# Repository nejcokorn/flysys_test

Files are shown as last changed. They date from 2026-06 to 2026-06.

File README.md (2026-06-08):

# FlySys Hardware Plan

Updated: 2026-06-08

This folder is intentionally a planning workspace only. The next hardware build will be created from scratch in Atopile. Old EasyEDA, KiCad, generated production files, and JLC-specific draft outputs are not part of the active design.

## Goal

Build a compact FlySys variometer board with:

- BLE-first telemetry and configuration.
- Accurate pressure-based vertical-speed sensing.
- 6-axis inertial sensing for filtering/orientation support.
- LiPo charging and battery operation.
- Loud firmware-controlled audio output.
- USB mass-storage device access for logs/configuration.
- Power button, hidden BOOT/RESET recovery controls, green power LED, blue BLE pairing LED, USB, and software-first firmware update access without debug pads.

## Selected Components

| Function | Selection | Supplier note |
| --- | --- | --- |
| MCU/BLE/Wi-Fi/USBMSD | Espressif `ESP32-S3-WROOM-1U-N8` | Use ESP32-S3 because USBMSD needs configurable USB device support. `N8` provides 8 MB flash and has no PSRAM. The `1U` variant uses the module U.FL/I-PEX MHF1 connector for an off-board antenna. |
| External antenna | Pulse `ANTX200P001B24003` | Off-board 2.4 GHz adhesive flat patch antenna for the WROOM-1U U.FL/I-PEX MHF1 connector. It is a DigiKey order item, not a PCB footprint. |
| Pressure sensors | 2 x Bosch `BMP581` | Dual altitude/variometer pressure sensors on the same I2C bus. `U5` uses address `0x46`; `U6` uses address `0x47`. |
| 6-axis IMU | Bosch `BMI323` | Primary accelerometer/gyro. |
| Magnetometer | Not fitted | Keep unpopulated I2C pads or optional footprint for future magnetometer. |
| Charger / power path | TI `BQ24075RGTR` | 1S LiPo charger with power-path management. |
| 3.3 V regulator | TI `TLV75533PDBVR` | Replaces `AP2112K-3.3TRG1` because AP2112 was 0 stock in the DigiKey.si audit. Recheck current and thermal margin with ESP32-S3 peaks. Add local bulk capacitance near the module. |
| USB | GCT `USB4105-GF-A` + ST `USBLC6-2SC6Y` | USB-C 2.0 receptacle and automotive/AEC-Q101 USB ESD for charging, ESP32-S3 native USB, USBMSD, logs, and flashing. |
| Audio | Same Sky `CSS-J4D20-SMT-TR` + `AO3400A` N-MOSFET | Externally driven SMD magnetic transducer from the old device BOM. Drive from the 1S battery/SYS rail; keep firmware tone, carrier-duty, and envelope control. |
| User input | C&K `KMR211NG LFS` | Momentary active-low tactile switch for power/user input plus hidden BOOT and RESET service switches. Final actuator and pinhole geometry still depends on enclosure height. |
| Indicators | Lite-On `LTST-C190GKT` + `LTST-C190TBKT` | 0603 LEDs: green always-on `+3V3` power-present indicator, blue firmware-controlled BLE pairing/advertising indicator. The blue LED is driven from `SYS` with a GPIO-controlled low-side MOSFET. |
| Battery | JST `S2B-PH-SM4-TB` | 2-pin JST-PH right-angle SMD header. Confirm protected pack and cable polarity. |
| Firmware update | Application-level updater + hidden ESP32-S3 BOOT/RESET recovery | Normal users update through firmware while USB or another supported link is connected. Debug pads are not fitted; hidden BOOT+RESET remains the recovery fallback for the ESP32-S3 ROM USB bootloader. |

## DigiKey.si Availability Audit

Initial audit checked: 2026-05-31. Audio and LED changes rechecked: 2026-06-01. Stock changes quickly; recheck before ordering.

| Function | MPN | DigiKey cut-tape part | Observed availability | Status |
| --- | --- | --- | --- | --- |
| MCU/BLE/Wi-Fi/USBMSD | `ESP32-S3-WROOM-1U-N8` | `1965-ESP32-S3-WROOM-1U-N8CT-ND` | Recheck before ordering | Selected external-antenna module |
| External antenna | `ANTX200P001B24003` | `311-1553-ND` | Recheck before ordering | Off-board U.FL/I-PEX MHF1 adhesive 2.4 GHz antenna |
| Pressure sensors | `BMP581` | `828-BMP581CT-ND` | Recheck before ordering | Qty 2 selected |
| 6-axis IMU | `BMI323` | `828-BMI323CT-ND` | 663 in stock | Selected |
| Charger / power path | `BQ24075RGTR` | `296-38874-1-ND` | 3,702 in stock | Selected |
| 3.3 V LDO | `TLV75533PDBVR` | `296-50411-1-ND` | 110,688 in stock | Selected |
| USB-C receptacle | `USB4105-GF-A` | `2073-USB4105-GF-ACT-ND` | 126,702 in stock | Selected |
| USB ESD | `USBLC6-2SC6Y` | `497-11882-1-ND` | 35,783 in stock | Selected automotive/AEC-Q101 part; LCSC `C2969755` |
| Battery connector | `S2B-PH-SM4-TB` | `455-S2B-PH-SM4-TBCT-ND` | 71,350 in stock | Selected |
| Loud SMD buzzer | `CSS-J4D20-SMT-TR` | `102-1198-1-ND` | 2,332 in stock | Selected old-device buzzer: externally driven magnetic transducer, 90 dB at 3.6 V, 5 cm, 80 mA, 3.1 kHz |
| N-MOSFETs | `AO3400A` | `785-1000-1-ND` | 168,023 in stock | Low-side drivers for buzzer PWM, blue BLE pairing LED switching, and power-latch control |
| Battery switch P-MOSFET | `DMP3098L-7` | `DMP3098LDICT-ND` | Recheck before ordering | High-side hard-off switch between battery connector and internal `BAT` rail |
| Power-start diodes | `1N4148W-7-F` | `1N4148W-FDICT-ND` | Recheck before ordering | Diode isolation for power button, battery switch gate, and charger `SYSOFF` |
| User button | `KMR211NG LFS` | `CKN10243CT-ND` | 44,917 in stock | Selected |
| Power LED | `LTST-C190GKT` | `160-LTST-C190GKTCT-ND` | 1,068,260 in stock | Selected 0603 green LED, 2.1 V typical Vf |
| BLE LED | `LTST-C190TBKT` | `160-1646-1-ND` | 92,246 in stock | Selected 0603 blue LED for BLE pairing/advertising indication, 3.3 V typical Vf |
| Resistors | Yageo `RC0603FR` 1% 0603 family | Value-specific | `RC0603FR-0710KL` observed at 9,468,329 in stock | Use same family for 100R, 1k, 3k, 5.1k, 10k, 100k, 1M as needed |
| 100 nF decoupling capacitor | Samsung `CL10B104KB8NNNC` | `1276-1000-1-ND` | 9,953,497 in stock | Selected family |
| Other ceramics | Samsung CL-series MLCCs | Value-specific | Not individually locked yet | Select exact 1 uF, 10 uF, and 220 nF parts during Atopile binding |

Main audit result: all selected active semiconductors, sensors, connector choices, audio parts, button, LED, and common passives are available from DigiKey.si.

## Baseline Electrical Architecture

- `USB_VBUS`: USB-C 5 V input to charger and USB VBUS sense divider/comparator.
- `SYS`: BQ24075 system output.
- `BAT_RAW`: protected 1S LiPo positive terminal at the connector.
- `BAT`: switched internal battery rail after the hard-off P-MOSFET.
- `+3V3`: TLV75533 output powering ESP32-S3, both BMP581 sensors, BMI323, and optional magnetometer pads.
- `I2C_SCL`, `I2C_SDA`: shared sensor bus for BMP581 `U5`, BMP581 `U6`, BMI323, and DNP magnetometer option.
- `USB_OTG_DP`, `USB_OTG_DM`: USB full-speed pair to ESP32-S3 native USB pins (`GPIO20` D+, `GPIO19` D-).
- `BUZZER_VM`: battery/SYS-powered audio rail feeding the buzzer; no boost in the baseline.
- `BUZZER_PWM`: ESP32-S3 PWM-capable GPIO to the MOSFET gate.
- `PWR_SW_N`: raw active-low power switch node.
- `PWR_BTN_N`: diode-isolated active-low button input to ESP32-S3.
- `BOOT_USER_BTN_N`: ESP32-S3 GPIO0 boot strap, pulled low by the hidden BOOT service button for ROM bootloader recovery.
- `BAT_SENSE`: high-value divider from switched `BAT` to ESP32-S3 ADC-capable GPIO; it has no DC path to `BAT_RAW` when the hard-off switch is open.
- `POWER_LED`: low-current green `+3V3` rail indicator with series resistor. It is on whenever `+3V3` is up and is not firmware-controlled.
- `BLE_LED`: low-current blue indicator for BLE pairing/advertising mode only. Firmware should drive `BLE_LED_PWM` active only while connectable BLE advertising/pairing is active and keep it low or high-Z otherwise. Because the blue LED has high forward voltage, prefer `SYS` plus a current-limit resistor and a small GPIO-controlled low-side switch instead of direct `+3V3` GPIO drive.
- `EN`, `BOOT`: hidden physical RESET and BOOT service controls for ESP32-S3 ROM bootloader recovery only.

## USBMSD / Storage Plan

USBMSD is now a baseline requirement. Use ESP32-S3 native USB OTG device mode with the ESP-IDF TinyUSB MSC class.

Route the USB-C D+/D- pair to ESP32-S3 `GPIO20`/`GPIO19`, keep the ESD part near the connector, and add a USB VBUS monitor path because this is a battery-powered, self-powered USB device.

Initial storage options:

- Internal flash FAT partition for small configuration import/export and short log files.
- External SPI flash, SPI NAND, or microSD if host-visible logs need materially more capacity or write endurance.

Do not let firmware and the USB host write the same mounted filesystem at the same time. Define a mode switch or mount arbitration before implementing firmware.

## Firmware Update UX

Normal firmware update is software-first. When USB is connected, application
firmware should expose an update path such as USB MSC drag-and-drop firmware
copy, a USB CDC update tool, BLE DFU, or OTA. The image must be validated before
activation, and firmware should use OTA partitions with rollback so a failed
image can revert automatically.

USB attach is allowed to power the ESP32-S3 electrically. If `USB_VBUS_SENSE`
shows USB present and the user has not pressed `POWER`, firmware enters
USB-attached idle mode instead of starting the vario application. In this mode,
do not start vario sensing, BLE advertising, buzzer output, logging, or normal
flight behavior. Only minimal charging/status indication, the firmware update
endpoint, and an optional command to start normal mode should run.

Pressing `POWER` while USB is connected records user intent and starts the normal
application. The hidden `BOOT` (`GPIO0`) and `RST` (`EN`) controls remain behind
service access only. Recovery sequence: connect USB-C, hold hidden `BOOT`, press
and release hidden `RST`, release `BOOT`, then flash with the ESP32-S3 native USB
ROM bootloader tool.

## Audio Plan

The buzzer must be loud enough for a paragliding vario used in open air with wind noise. Treat acoustic output as a primary requirement, not a secondary indicator.

Use an externally driven passive SMD transducer so firmware keeps control over pitch, cadence, envelope, mute profiles, and sink/climb tone patterns. Do not use an internally driven active buzzer.

Selected audio path:

- Transducer: `CSS-J4D20-SMT-TR`, externally driven magnetic SMD transducer from the old device BOM, 90 dB at 3.6 V, 5 cm, 3.1 kHz, about 80 mA at rated drive.
- Driver: `AO3400A` low-side N-MOSFET, with the buzzer powered from the 1S battery/SYS rail and the MOSFET gate driven by one ESP32-S3 PWM GPIO.

This matches the old `MX270_MiniUP` firmware model: one output-compare PWM channel generated the audio carrier, `beep->volume` changed the carrier duty, and the vario queue changed the beep envelope/cadence. Port that control model to ESP32-S3 LEDC or MCPWM.

Use the battery/SYS rail, not raw USB VBUS. A normal 1S Li-ion/LiPo pack is 4.2 V full and about 3.6-3.7 V nominal; that fits the buzzer's 3-5 V operating range. Confirm BQ24075 `SYS` behavior so the buzzer never sees an out-of-range USB-derived rail.

Drive the buzzer near its 3.1 kHz rated frequency for maximum SPL. For lower volume, prefer carrier-duty control and audible envelope control; avoid detuning far from resonance just to reduce volume. The old firmware's tone table can be reused as a behavioral reference, but final tones should be revalidated against this buzzer in the enclosure.

Add a gate resistor, gate pulldown, local bulk capacitance near the buzzer supply, and a footprint option for coil clamp/snubber parts. Keep the buzzer current loop compact and scope the first PCB for ringing and EMI while the buzzer is running.

The enclosure must include a real acoustic outlet or sound channel. Verify SPL after the PCB is installed in the actual enclosure, because the port, chamber volume, venting, clothing, helmet, and mounting orientation can dominate the result.

## Sensor Plan

Use two BMP581 barometers and one BMI323 as the fitted sensor stack.

`U5` straps `SDO` to `GND` for BMP581 I2C address `0x46`; `U6` straps `SDO` to `+3V3` for address `0x47`. Both sensors strap `CSB` high for I2C mode and have separate interrupt nets, `BMP581_1_INT` and `BMP581_2_INT`.

Do not fit a magnetometer for the first Atopile board. The core variometer behavior depends on pressure and vertical-motion filtering, not absolute compass heading. Without a magnetometer, yaw/heading can drift; that is acceptable for this baseline.

Keep an unpopulated future magnetometer option with:

- `+3V3`
- `GND`
- `I2C_SCL`
- `I2C_SDA`
- Optional `MAG_INT`

Place the optional magnetometer pads away from USB shield, charger, buzzer, battery current loops, steel screws, and magnets.

## Layout Constraints

- Put the ESP32-S3-WROOM-1U-N8 so its U.FL/I-PEX MHF1 connector is accessible for the off-board antenna cable. Provide coax strain relief and keep the antenna away from battery metal, buzzer metal, enclosure metal, and the user's body as much as the enclosure allows.
- Put both BMP581 sensors near the pressure vent and away from heat, board flex, adhesive, conformal coating, and direct buzzer airflow.
- Put BMI323 near the board center in a mechanically stable area and document axis orientation.
- Keep sensor supply decoupling close to each VDD/VDDIO pin.
- Keep USB D+/D- short, impedance-conscious, protected by ESD near the connector, and routed to ESP32-S3 `GPIO20`/`GPIO19`.
- Include USB VBUS monitoring suitable for self-powered USB device behavior.
- Give the buzzer a clear acoustic outlet; do not bury the port in a sealed or foam-covered enclosure pocket.
- Keep buzzer switching current and charger return currents away from sensor ground return.
- Avoid assigning functional loads to ESP32-S3 boot strapping pins, USB pins, and flash/PSRAM-reserved pins until boot behavior and the exact module variant are checked.

## Firmware Impact

- Port board support from Arduino Nano 33 BLE Sense Rev2 / nRF52840 assumptions to ESP32-S3.
- Use ESP32-S3 BLE stack and keep transmission duty cycle low in production.
- Add USBMSD using ESP-IDF TinyUSB MSC over ESP32-S3 native USB OTG.
- Define the USBMSD storage backend and host-visible filesystem.
- Prevent concurrent writes between firmware logging/config code and the mounted USB host filesystem.
- Decide whether USB presents MSC only, CDC+MSC composite, or a boot/mode-selected function.
- Add software-first firmware update handling with image validation and OTA partition rollback.
- On USB attach from off state, enter USB-attached idle mode until `PWR_BTN_N` is pressed or a supported start command is received.
- In USB-attached idle mode, keep vario sensing, BLE normal operation, buzzer output, and logging inactive.
- Add direct dual-BMP581 driver support for I2C addresses `0x46` and `0x47`, including separate `BMP581_1_INT` and `BMP581_2_INT` handling.
- Add direct BMI323 driver support.
- Remove required magnetometer reads from the baseline firmware path.
- Rework GPIO mapping for ESP32-S3, including `BUZZER_PWM`, `PWR_BTN_N`, `PWR_HOLD`, `BAT_SENSE`, `BLE_LED_PWM`, I2C, USB, `EN`, and `BOOT`.
- Add configurable audio profiles for vario use: climb cadence, sink alarm, mute, startup check, and volume/power-saving modes.
- Port the old single-PWM buzzer model, then retune frequency and volume tables around the `CSS-J4D20-SMT-TR` response on the new PCB.
- Revalidate sensor axis mapping and calibration on the actual PCB.

## Open Decisions

- Protected LiPo pack and cable polarity.
- USBMSD storage backend: internal flash FAT partition vs external flash/NAND/microSD.
- USB device mode policy: MSC only, CDC+MSC composite, boot/mode-selected function, and the exact software update endpoint.
- Final volume-control policy: envelope levels, quiet mode, and startup volume.
- Enclosure acoustic outlet, port orientation, and measured SPL after installation.
- Button actuator/enclosure mechanics.
- Final ESP32-S3 GPIO map after strapping-pin, USB-pin, and reserved-pin review.
- Whether `ESP32-S3-WROOM-1U-N8` without PSRAM is sufficient for the final USBMSD firmware.
- RF/EMC certification path for the selected 4.4 dBi external antenna. Espressif's module certification guidance recommends antennas no higher than the certified antenna gain, so this antenna choice may require additional testing.
- TLV75533 current and thermal margin with ESP32-S3 RF peaks and USB-attached operation.
- Whether charger status pins need LEDs or only test pads.
- Final Atopile package/footprint sources and exact passive values.

## Atopile Build Order

1. Create Atopile project scaffold.
2. Add verified packages for ESP32-S3-WROOM-1U-N8, two BMP581 sensors, BMI323, BQ24075, TLV75533, USB-C, USB ESD, LiPo connector, CSS-J4D20 buzzer, MOSFET driver, button, green power LED, blue BLE pairing LED, passives, and the BOM-only external antenna.
3. Capture power path and 3.3 V rail.
4. Capture ESP32-S3 native USB OTG, USB VBUS sense, `EN`, `BOOT`, and hidden service bootloader buttons.
5. Capture both BMP581 sensors and BMI323 on shared I2C.
6. Add unpopulated magnetometer I2C pads or optional footprint.
7. Add the selected USBMSD storage backend if external storage is selected.
8. Capture loud audio and user I/O.
9. Assign supplier/manufacturer metadata for audit.
10. Run electrical/package checks before PCB routing.

## Atopile Project Status

Atopile is now the active project source in this repo:

- `ato.yaml`: Atopile 0.15.7 project config.
- `main.ato`: FlySysVario schematic source and Atopile `RectangularBoardShape` board outline.
- `parts/`: generated and local part definitions, including local draft footprints for battery, buzzer, MOSFETs, signal diodes, buttons, and optional magnetometer pads.
- `layouts/default/default.kicad_pcb`: Atopile-generated layout artifact used by the Atopile Autolayout panel.
- `docs/components-and-placement.md`: component map, passive explanations, and placement intent.

Current modeled nets include USB-C, USB ESD, BQ24075 power path, P-MOS battery hard-off switch, TLV75533 3.3 V rail, ESP32-S3 native USB, I2C sensor bus, two BMP581 barometers, BMI323, battery connector, switched battery/USB sense dividers, buzzer MOSFET driver, always-on green power LED, blue BLE pairing LED low-side switch, power/user button, hidden BOOT and RESET service buttons, and optional future magnetometer pads. See `docs/firmware-update-ux.md` for the software-first update flow and recovery fallback.

`ato --non-interactive build --standalone main.ato:FlySysVario` completes the
current Atopile source workflow. The default layout build still needs a layout
artifact migration after the WROOM-1U swap; `ato --non-interactive build`
passes electrical verification but fails while loading `layouts/default/default.kicad_pcb`.
The 90 mm x 45 mm board outline is defined in `main.ato` with
`RectangularBoardShape`, so the Atopile Autolayout panel has a board boundary to
place and route against. The remaining warnings are expected for local or
DigiKey-only parts because the current picker support is not covering those
local packages. Before production, verify the local draft footprints for
`ESP32-S3-WROOM-1U-N8`, `S2B-PH-SM4-TB`, `CSS-J4D20-SMT-TR`, `AO3400A`,
`DMP3098L`, `1N4148W`, `KMR211NG LFS`, and optional magnetometer pads against
manufacturer land patterns and enclosure mechanics.

## Source Links

- Atopile project structure: https://docs.atopile.io/atopile-0.14.x/essentials/5-project-structure
- Atopile language reference: https://docs.atopile.io/atopile-0.14.x/essentials/1-the-ato-language
- ESP32-S3-WROOM-1/WROOM-1U datasheet: https://documentation.espressif.com/esp32-s3-wroom-1_wroom-1u_datasheet_en.pdf
- DigiKey.si ESP32-S3-WROOM-1U-N8: https://www.digikey.si/en/products/detail/espressif-systems/ESP32-S3-WROOM-1U-N8/16162635
- DigiKey.si Pulse ANTX200P001B24003: https://www.digikey.si/en/products/detail/pulse-electronics/ANTX200P001B24003/3927174
- ESP-IDF ESP32-S3 USB Device Stack / TinyUSB MSC: https://docs.espressif.com/projects/esp-usb/en/latest/esp32s3/usb_device.html
- ESP-IDF ESP32-C3 USB Serial/JTAG fixed-function note: https://docs.espressif.com/projects/esp-idf/en/release-v5.2/esp32c3/api-guides/usb-serial-jtag-console.html
- Bosch BMP581: https://www.bosch-sensortec.com/en/products/environmental-sensors/pressure-sensors/bmp581/
- Bosch BMP581 datasheet / land pattern: https://www.bosch-sensortec.com/media/boschsensortec/downloads/datasheets/bst-bmp581-ds004.pdf
- DigiKey.si BMP581: https://www.digikey.si/en/products/detail/bosch-sensortec/BMP581/16036134
- Bosch BMI323: https://www.bosch-sensortec.com/en/products/motion-sensors/imus/bmi323/
- DigiKey.si BMI323: https://www.digikey.si/en/products/detail/bosch-sensortec/BMI323/16719593
- TI BQ24075: https://www.ti.com/product/BQ24075
- DigiKey.si BQ24075RGTR: https://www.digikey.si/en/products/detail/texas-instruments/BQ24075RGTR/2047273
- DigiKey.si TLV75533PDBVR: https://www.digikey.si/en/products/detail/texas-instruments/TLV75533PDBVR/9356541
- DigiKey.si USB4105-GF-A: https://www.digikey.si/en/products/detail/gct/USB4105-GF-A/11198441
- DigiKey.si USBLC6-2SC6Y: https://www.digikey.si/en/products/detail/stmicroelectronics/USBLC6-2SC6Y/2819177
- DigiKey.si S2B-PH-SM4-TB: https://www.digikey.si/en/products/filter/headers-male-pins/314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
- DigiKey.si CSS-J4D20-SMT-TR: https://www.digikey.si/en/products/detail/same-sky-formerly-cui-devices/CSS-J4D20-SMT-TR/504819
- DigiKey.si AO3400A: https://www.digikey.si/en/products/detail/alpha-omega-semiconductor-inc/AO3400A/1855772
- DigiKey.si KMR211NG LFS: https://www.digikey.si/en/products/detail/c-k/Y78B21120FP/2176482
- DigiKey.si LTST-C190GKT: https://www.digikey.si/en/products/detail/lite-on-inc/LTST-C190GKT/269230
- DigiKey.si LTST-C190TBKT: https://www.digikey.si/en/products/detail/lite-on-inc/LTST-C190TBKT/388529
- DigiKey.si RC0603FR resistor family: https://www.digikey.si/en/products/filter/chip-resistor-surface-mount/52
- DigiKey.si CL10B104KB8NNNC: https://www.digikey.si/en/products/detail/samsung-electro-mechanics/CL10B104KB8NNNC/3886658

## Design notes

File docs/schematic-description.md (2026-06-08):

# FlySys Schematic Description

Updated: 2026-06-08

This document describes the KiCad schematic in text form. The schematic file is
`kicad/flysys_vario.kicad_sch`; the Atopile source net plan is `main.ato`.

## Functional Blocks

FlySys is a small BLE/USB variometer board built around `U4`, an
`ESP32-S3-WROOM-1U-N8` module with an external U.FL/I-PEX MHF1 antenna
connector. Power enters from USB-C at `USB1` or from a LiPo
battery at `J1`. `U1` manages LiPo charging and the system power path, `U3`
generates the regulated `+3V3` rail, `U5` and `U6` measure pressure for
altitude/vario data, `U2` provides IMU motion data, and `BZ1` gives loud
acoustic feedback.

The board uses the following main nets:

| Net | Meaning |
| --- | --- |
| `USB_VBUS` | 5 V from USB-C connector. Feeds charger input and USB VBUS sense divider. |
| `BAT_RAW` | LiPo battery positive terminal at `J1`, before the hard-off battery switch. |
| `BAT` | Switched internal battery rail after `Q4`. Feeds charger battery pin and battery ADC divider only while the battery switch is on. |
| `SYS` | Charger power-path output. Feeds 3.3 V regulator and high-current buzzer/blue LED loads when the system is on. |
| `+3V3` | Regulated logic rail for ESP32-S3, both pressure sensors, IMU, pull-ups, and the green power LED. |
| `CHG_SYSOFF` | BQ24075 ship-mode control. High disconnects battery from `SYS`; low enables battery-to-`SYS` operation. |
| `PWR_SW_N` | Raw active-low power button node from `SW1`, isolated from MCU and latch nodes by diodes. |
| `PWR_BTN_N` | Isolated active-low power/user button input read by the MCU on `IO7`. |
| `USB_VBUS_SENSE` | Divided USB VBUS monitor read by the MCU on `IO2`. Firmware uses it to detect USB-attached idle/update mode. |
| `PWR_HOLD` | MCU `IO10` output that can release the self-latching power circuit by driving `PWR_HOLD_GATE` low. |
| `BMP581_1_INT` | Interrupt output from `U5` BMP581 to MCU `IO4`. |
| `BMP581_2_INT` | Interrupt output from `U6` BMP581 to MCU `IO16`. |
| `BAT_SWITCH_GATE` | Gate of the battery high-side P-channel MOSFET `Q4`. |
| `GND` | Common ground and USB shield reference. |

## USB-C And ESD

`USB1` is the USB-C device connector. `CC1` and `CC2` are each pulled down to
ground by `R9` and `R10`, both 5.1 kohm, so the board presents itself as a USB
device/sink.

USB data exits the connector as `USB_DP_CONN` and `USB_DM_CONN`, passes through
`D1` (`USBLC6-2SC6Y`) for ESD protection, then continues to the ESP32-S3 as
`USB_OTG_DP` and `USB_OTG_DM`. `D1` must stay physically between `USB1` and
`U4`, close to the connector, so ESD current is shunted before it reaches the
MCU.

The USB-C shell/mechanical pads are tied to `GND`. The local USB footprint maps
all shell pads to the same symbol pin so KiCad does not leave shield pads
unconnected during PCB update.

## Charger And Power Path

`U1` (`BQ24075RGTR`) receives `USB_VBUS` on `IN`, connects to the switched
internal battery rail on `BAT`, and produces the system rail on `OUT`/`SYS`.
The charger is enabled by tying `nCE` low. `EN1`, `EN2`, `TS`, `ISET`, `ILIM`,
and `TMR` are configured with fixed resistors, so the current limits and timer
behavior are set in hardware.

`Q4` (`DMP3098L`) is a high-side P-channel MOSFET between `BAT_RAW` and `BAT`.
`R28` pulls `BAT_SWITCH_GATE` up to `BAT_RAW`, so the default battery-only state
physically disconnects the battery from the BQ24075 `BAT` pin and from the
`BAT_SENSE` divider. In this state the board has no intentional DC battery load;
only MOSFET/diode leakage remains.

`SYSOFF` is still used as the BQ24075 power-path off control. `R23` pulls
`CHG_SYSOFF` up to the switched `BAT` rail, while `Q3` pulls it low when the
power latch is active. Pressing `SW1` grounds `PWR_SW_N`; `D3` pulls
`BAT_SWITCH_GATE` low to turn `Q4` on, and `D4` pulls `CHG_SYSOFF` low so
`SYS` turns on from the battery. Once `+3V3` is up, `R24` pulls
`PWR_HOLD_GATE` high and turns on both `Q3` and `Q5`, which latches
`CHG_SYSOFF` and `BAT_SWITCH_GATE` low after `SW1` is released. `R26` keeps the
latch off before `+3V3` is present.

Firmware can shut the board down from battery power by driving `IO10`
(`PWR_HOLD`) low through `R25`; this turns off `Q3` and `Q5`, after which `R23`
and `R28` return the charger and battery switch to their off states. During
normal operation and during the ESP32-S3 ROM bootloader, `PWR_HOLD` may remain
high impedance because `R24` provides the hardware hold.

When USB is present, the BQ24075 can still power `SYS` from `USB_VBUS`. Firmware
should keep the latch active while battery charging is desired so `Q4` is on and
the BQ24075 `BAT` pin is connected to the pack.

`nCHG` and `nPGOOD` are open-drain charger status outputs. `R13` and `R19` pull
them up to `+3V3`, and the MCU reads them on GPIOs. These nets should not be
pulled to `SYS` because the ESP32-S3 GPIOs are 3.3 V only.

`J1` is the 2-pin LiPo connector. `BAT_POS` goes to `BAT_RAW`, and `BAT_NEG`
goes to `GND`. The final build must confirm connector polarity against the
actual battery harness before ordering or assembly.

## 3.3 V Regulation

`U3` (`TLV75533PDBVR`) converts `SYS` into `+3V3`. The regulator enable pin is
tied to `SYS`, so the 3.3 V rail is on whenever `SYS` is present. On battery
power, `SYS` is present only after `CHG_SYSOFF` is pulled low by `SW1` or `Q3`.

`+3V3` powers the ESP32-S3 module, both BMP581 pressure sensors, BMI323 IMU,
I2C pull-ups, charger status pull-ups, the always-on green power LED, and
button/latch pull-ups.

## ESP32-S3 MCU

`U4` is the main controller. It uses native USB through `USB_OTG_DP` and
`USB_OTG_DM`, reads battery and USB voltage dividers, reads charger status, runs
the I2C sensor bus, drives the buzzer PWM MOSFET, and drives the BLE
pairing/advertising LED MOSFET.

The fitted module is `ESP32-S3-WROOM-1U-N8`. Its onboard U.FL/I-PEX MHF1
connector mates to the BOM-only external antenna `ANT1`
(`ANTX200P001B24003`). `ANT1` is not a PCB footprint. The selected antenna has
4.4 dBi gain, so RF/EMC approval needs a separate review against the target
certification path.

`EN` has a 10 kohm pull-up (`R16`) and 100 nF capacitor (`C4`) for a simple reset
RC network. `SW3` pulls `EN` low for a hidden service reset button labeled
`RST` on the PCB.

`BOOT_USER_BTN_N` is pulled up by `R6` and pulled low by `SW2`. `SW2` is a
hidden service `BOOT` button, not a normal user update control. To enter the
ESP32-S3 ROM USB bootloader for recovery, connect USB-C, hold `SW2` (`BOOT`),
press and release `SW3` (`RST`), then release `BOOT`. If a service setup must
keep the board powered from battery before USB is attached, press `SW1` first to
latch power; recovery flashing still requires USB. No debug pads are fitted.

`SW1` is the active-low power button on `PWR_SW_N`. `D2` lets the MCU read this
button as `PWR_BTN_N` on `IO7` while preventing `BAT_RAW` or latch nodes from
feeding the unpowered MCU in hard-off.

## Firmware Update And USB-Attached Idle UX

Normal firmware update is software-first. Application firmware should expose an
update endpoint such as USB MSC drag-and-drop, USB CDC update tooling, BLE DFU,
or OTA. Firmware must validate the image before activating it and should use OTA
partitions with rollback so a failed update returns to the previous working
image.

USB attach is allowed to power the ESP32-S3 electrically through the charger
power path. On boot, firmware must read `USB_VBUS_SENSE` and the current or
persisted power-intent state. If USB is present and the user has not pressed
`POWER`, firmware enters USB-attached idle mode rather than starting the vario
application.

In USB-attached idle mode, firmware must not start pressure/IMU vario sensing,
BLE advertising or normal telemetry, buzzer output, flight logging, or normal
flight behavior. Only minimal charging/status indication, the firmware update
endpoint, and an optional command to start normal mode should run. Pressing
`SW1` drives `PWR_BTN_N` low; firmware records this user intent and starts the
normal application.

The hidden `BOOT` + `RST` sequence remains the documented recovery fallback only
when the application updater is unavailable or application firmware is broken.
See `docs/firmware-update-ux.md` for the service flow and verification plan.

## Sensor Bus

`U5` (`BMP581`), `U6` (`BMP581`), and `U2` (`BMI323`) share the I2C bus:

| Net | MCU | Loads |
| --- | --- | --- |
| `I2C_SCL` | ESP32-S3 `IO8` | `U5 SCK`, `U6 SCK`, `U2 SCX`, pull-up `R17` |
| `I2C_SDA` | ESP32-S3 `IO9` | `U5 SDI`, `U6 SDI`, `U2 SDX`, pull-up `R18` |

Both pull-ups are 4.7 kohm to `+3V3`. `U5 SDO` is tied to `GND` for BMP581 I2C
address `0x46`; `U6 SDO` is tied to `+3V3` for address `0x47`. `BMI323 SDO` is
tied to `GND`. All sensor chip-select pins are tied high so the devices remain
in I2C mode. Sensor interrupt pins are routed independently to ESP32 GPIOs for
firmware use.

## Buzzer Driver

`BZ1` is powered from `SYS`, not from `+3V3`, so it can use the higher available
system voltage and avoid loading the LDO. `Q1` (`AO3400A`) is a low-side
N-channel MOSFET controlled by ESP32 PWM through `R8`. `R7` pulls the MOSFET
gate down so the buzzer stays off while the MCU is reset or booting.

The buzzer current loop is `SYS -> BZ1 -> Q1 -> GND`. This loop must be compact
and kept away from the pressure sensor and I2C lines.

## LEDs

`LED2` is the green power LED. It is powered from `+3V3` through `R20`, then
returns directly to `GND`. It is a power-present indicator and is on whenever
`+3V3` is up; firmware does not control it.

`LED1` is the blue BLE pairing LED. It is powered from `SYS` through `R5` and
switched by `Q2`, another low-side `AO3400A`. `R4` is the series gate resistor,
and `R3` is the gate pulldown. This keeps the LED off while the ESP32-S3 GPIO is
high impedance. Firmware should drive `BLE_LED_PWM` active only while BLE
pairing/connectable advertising mode is active, and keep it low or high-Z
otherwise.

## Capacitors And Their Roles

| Ref | Value | Net | Role |
| --- | --- | --- | --- |
| `C14` | 1 uF | `USB_VBUS` to `GND` | USB input decoupling. It supplies short input-current pulses and should sit close to `USB1`/`U1 IN`. |
| `C1` | 10 uF | `BAT` to `GND` | Switched battery rail bulk capacitance. It stabilizes the charger battery pin after `Q4` is on. |
| `C13` | 10 uF | `SYS` to `GND` | Main system rail bulk. It helps the charger power-path output handle load changes from the LDO and buzzer. |
| `C7` | 1 uF | `SYS` to `GND` | LDO input capacitor. It must be placed at `U3 IN/GND` to keep the regulator stable. |
| `C8` | 1 uF | `+3V3` to `GND` | LDO output capacitor. It must be placed at `U3 OUT/GND` to meet regulator stability requirements. |
| `C9` | 10 uF | `+3V3` to `GND` | ESP32-S3 local bulk capacitor. It supports RF and CPU current bursts. |
| `C10` | 100 nF | `+3V3` to `GND` | ESP32-S3 high-frequency decoupling. It should be very close to the module power pin. |
| `C12` | 100 nF | `U5 BMP581 VDD` to `GND` | First pressure sensor core decoupling. Place next to `U5`. |
| `C11` | 100 nF | `U5 BMP581 VDDIO` to `GND` | First pressure sensor I/O decoupling. Place next to `U5`. |
| `C15` | 100 nF | `U6 BMP581 VDD` to `GND` | Second pressure sensor core decoupling. Place next to `U6`. |
| `C16` | 100 nF | `U6 BMP581 VDDIO` to `GND` | Second pressure sensor I/O decoupling. Place next to `U6`. |
| `C6` | 100 nF | `BMI323 VDD` to `GND` | IMU core decoupling. Place next to `U2`. |
| `C5` | 100 nF | `BMI323 VDDIO` to `GND` | IMU I/O decoupling. Place next to `U2`. |
| `C3` | 10 uF | `SYS` to `GND` | Local buzzer reservoir. Place close to `BZ1` and `Q1` so buzzer current does not disturb the rest of `SYS`. |
| `C4` | 100 nF | `EN` to `GND` | ESP32-S3 enable/reset RC capacitor with `R16`. Place close to `U4 EN`. |
| `C2` | 100 nF | `BAT_SENSE` to `GND` | ADC filter for the switched-battery divider midpoint. Place near `R1`/`R2` and the MCU ADC input. |

## No-Connect Rules

Every intentionally unused schematic pin must be marked as no-connect in KiCad.
Do not silently leave an unused pin without either a net label or a no-connect
marker.

`NC` means no copper connection: do not tie the pin to `GND`, `+3V3`, `SYS`, or
any other net unless the datasheet explicitly asks for it. Do not add test pads
to `NC` pins unless the schematic is updated to document that future option.

For this design, the intentionally unused pins are:

| Component | Pins | Required treatment |
| --- | --- | --- |
| `USB1` | `A8`, `B8` | USB-C SBU pins are unused. Leave floating and mark no-connect. |
| `U3` | `4` | TLV75533 `NC` pin. Leave floating and mark no-connect. |
| `U4` | `8`, `15`, `16`, `19`, `20`, `21`, `22`, `23`, `24`, `25`, `26`, `28`, `29`, `32`, `33`, `34`, `35`, `36`, `37` | Unused ESP32-S3 GPIO/module pins. Leave floating and mark no-connect. Do not tie unused GPIOs to rails in hardware. |
| `U2` | `2`, `3`, `10`, `11` | BMI323 datasheet NC pins. Leave floating and mark no-connect. |

The USB-C shell pads are not `NC`; they are part of the connector shield and are
tied to `GND`.

## Component Pin Connection Instructions

The tables below define what every component pin must connect to in the
schematic and PCB. `NC` rows follow the no-connect rules above.

### Connectors And Protection

| Ref | Pin | Pin name | Connect to | Instruction |
| --- | --- | --- | --- | --- |
| `USB1` | `1` | `EH` | `GND` | USB-C shell/edge hardware ground. All shell mounting pads in the footprint are mapped to this grounded pin. |
| `USB1` | `A1`, `A12`, `B1`, `B12` | `GND` | `GND` | Connector signal grounds. Tie directly to the ground plane. |
| `USB1` | `A4`, `A9`, `B4`, `B9` | `VBUS` | `USB_VBUS` | USB 5 V input. Route to `U1 IN`, `D1 VBUS`, `C14`, and USB VBUS sense divider. |
| `USB1` | `A5` | `CC1` | `CC1` | Connect only to `R9`, then to `GND`. |
| `USB1` | `B5` | `CC2` | `CC2` | Connect only to `R10`, then to `GND`. |
| `USB1` | `A6`, `B6` | `DP1`, `DP2` | `USB_DP_CONN` | Connector-side USB D+. Route to `D1` first. |
| `USB1` | `A7`, `B7` | `DN1`, `DN2` | `USB_DM_CONN` | Connector-side USB D-. Route to `D1` first. |
| `USB1` | `A8`, `B8` | `SBU1`, `SBU2` | `NC` | Leave floating; this board does not use USB-C alternate modes. |
| `D1` | `1` | `IO1_A` | `USB_DP_CONN` | Connector-side D+ input to ESD device. |
| `D1` | `2` | `GND` | `GND` | Short ESD return to ground. |
| `D1` | `3` | `IO2_A` | `USB_DM_CONN` | Connector-side D- input to ESD device. |
| `D1` | `4` | `IO2_B` | `USB_OTG_DM` | MCU-side D- output from ESD device. |
| `D1` | `5` | `VBUS` | `USB_VBUS` | ESD reference to USB VBUS. |
| `D1` | `6` | `IO1_B` | `USB_OTG_DP` | MCU-side D+ output from ESD device. |
| `J1` | `1` | `BAT+` | `BAT_RAW` | LiPo positive terminal before the hard-off battery switch. Confirm pack polarity before assembly. |
| `J1` | `2` | `BAT-` | `GND` | LiPo negative terminal. |

### Power Management

| Ref | Pin | Pin name | Connect to | Instruction |
| --- | --- | --- | --- | --- |
| `U1` | `1` | `TS` | `CHG_TS` | Connect to `R15` then `GND`. This is the fixed TS bias for no pack thermistor. |
| `U1` | `2`, `3` | `BAT` | `BAT` | Battery charger node. Keep short to `J1` and `C1`. |
| `U1` | `4` | `nCE` | `GND` | Charger enabled. |
| `U1` | `5` | `EN2` | `SYS` | Charger input-current mode strap. |
| `U1` | `6` | `EN1` | `GND` | Charger input-current mode strap. |
| `U1` | `7` | `nPGOOD` | `nPGOOD` | Open-drain status output. Pull up through `R19` to `+3V3`; also route to `U4`. |
| `U1` | `8` | `VSS` | `GND` | Ground. |
| `U1` | `9` | `nCHG` | `nCHG` | Open-drain charge status output. Pull up through `R13` to `+3V3`; also route to `U4`. |
| `U1` | `10`, `11` | `OUT` | `SYS` | Charger system output. Keep wide to `U3`, `C13`, buzzer, and LED load. |
| `U1` | `12` | `ILIM` | `CHG_ILIM` | Connect to `R11` then `GND`. |
| `U1` | `13` | `IN` | `USB_VBUS` | USB input power. Keep short to `USB1` and `C14`. |
| `U1` | `14` | `TMR` | `CHG_TMR` | Connect to `R14` then `GND`. |
| `U1` | `15` | `SYSOFF` | `CHG_SYSOFF` | Ship-mode control. High disconnects battery from `SYS`; low enables battery-to-`SYS` operation. |
| `U1` | `16` | `ISET` | `CHG_ISET` | Connect to `R12` then `GND`. |
| `U1` | `17` | `EP` | `GND` | Exposed pad. Stitch to ground plane for thermal and electrical return. |
| `Q4` | `1` | `G` | `BAT_SWITCH_GATE` | P-channel battery switch gate. Pull high to `BAT_RAW` for off, pull low to connect `BAT_RAW` to `BAT`. |
| `Q4` | `2` | `S` | `BAT_RAW` | P-channel source to raw battery connector positive. |
| `Q4` | `3` | `D` | `BAT` | P-channel drain to switched internal battery rail. |
| `Q5` | `1` | `G` | `PWR_HOLD_GATE` | N-channel gate driven by the hardware hold node. |
| `Q5` | `2` | `S` | `GND` | Low-side switch source. |
| `Q5` | `3` | `D` | `BAT_SWITCH_GATE` | Pulls `Q4` gate low while the power latch is active. |
| `U3` | `1` | `IN` | `SYS` | LDO input. Place `C7` at this pin. |
| `U3` | `2` | `GND` | `GND` | LDO ground. |
| `U3` | `3` | `EN` | `SYS` | LDO enabled whenever `SYS` is present. |
| `U3` | `4` | `NC` | `NC` | Leave floating and mark no-connect. |
| `U3` | `5` | `OUT` | `+3V3` | Regulated logic rail. Place `C8` at this pin. |

### ESP32-S3 Module

| Ref | Pin | Pin name | Connect to | Instruction |
| --- | --- | --- | --- | --- |
| `U4` | `1`, `40`, `41` | `GND`, `EPAD/GND` | `GND` | Tie all module grounds and the exposed pad to the ground plane. Do not leave any ground pad isolated. |
| `U4` | `2` | `3V3` | `+3V3` | Main module supply. Place `C9` and `C10` close to the module. |
| `U4` | `3` | `EN` | `EN` | Module enable/reset net with `R16` pull-up and `C4` to ground. |
| `U4` | `4` | `IO4` | `BMP581_1_INT` | First pressure sensor interrupt input from `U5`. |
| `U4` | `5` | `IO5` | `BMI323_INT1` | IMU interrupt input 1. |
| `U4` | `6` | `IO6` | `BMI323_INT2` | IMU interrupt input 2. |
| `U4` | `7` | `IO7` | `PWR_BTN_N` | Active-low power/user button input from `SW1`. |
| `U4` | `8` | `IO15` | `NC` | Leave floating and mark no-connect. |
| `U4` | `9` | `IO16` | `BMP581_2_INT` | Second pressure sensor interrupt input from `U6`. |
| `U4` | `10` | `IO17` | `BUZZER_PWM` | PWM output to `Q1` through `R8`. |
| `U4` | `11` | `IO18` | `BLE_LED_PWM` | BLE pairing/advertising LED control output to `Q2` through `R4`. |
| `U4` | `12` | `IO8` | `I2C_SCL` | I2C clock with pull-up `R17`. |
| `U4` | `13` | `IO19` | `USB_OTG_DM` | Native USB D-. Route as controlled short USB pair with pin 14. |
| `U4` | `14` | `IO20` | `USB_OTG_DP` | Native USB D+. Route as controlled short USB pair with pin 13. |
| `U4` | `15` | `IO3` | `NC` | Leave floating and mark no-connect; this is a strapping-sensitive GPIO. |
| `U4` | `16` | `IO46` | `NC` | Leave floating and mark no-connect; do not drive this strapping-sensitive GPIO high during reset. |
| `U4` | `17` | `IO9` | `I2C_SDA` | I2C data with pull-up `R18`. |
| `U4` | `18` | `IO10` | `PWR_HOLD` | Power-hold release output. Leave high-Z/high for normal hold; drive low to shut down from battery. |
| `U4` | `19`, `20`, `21`, `22` | `IO11`, `IO12`, `IO13`, `IO14` | `NC` | Leave floating and mark no-connect. |
| `U4` | `23`, `24`, `25` | `IO21`, `IO47`, `IO48` | `NC` | Leave floating and mark no-connect. |
| `U4` | `26` | `IO45` | `NC` | Leave floating and mark no-connect; this is a strapping-sensitive GPIO. |
| `U4` | `27` | `IO0` | `BOOT_USER_BTN_N` | Boot-mode strap/recovery net with pull-up `R6`; not connected to `SW1`. |
| `U4` | `28`, `29` | `IO35`, `IO36` | `NC` | Leave floating and mark no-connect. |
| `U4` | `30` | `IO37` | `nCHG` | Charger status input from `U1`, pulled up to `+3V3` by `R13`. |
| `U4` | `31` | `IO38` | `nPGOOD` | Charger power-good input from `U1`, pulled up to `+3V3` by `R19`. |
| `U4` | `32`, `33`, `34`, `35` | `IO39`, `IO40`, `IO41`, `IO42` | `NC` | Leave floating and mark no-connect. |
| `U4` | `36` | `RXD0` | `NC` | Debug pads are not fitted. Leave floating and mark no-connect. |
| `U4` | `37` | `TXD0` | `NC` | Debug pads are not fitted. Leave floating and mark no-connect. |
| `U4` | `38` | `IO2` | `USB_VBUS_SENSE` | USB VBUS ADC sense divider midpoint. Firmware uses this to enter USB-attached idle/update mode. |
| `U4` | `39` | `IO1` | `BAT_SENSE` | Battery ADC sense divider midpoint with filter `C2`. |

### Sensors

| Ref | Pin | Pin name | Connect to | Instruction |
| --- | --- | --- | --- | --- |
| `U5` | `1` | `VDDIO` | `+3V3` | First pressure sensor I/O supply. Decouple with `C11`. |
| `U5` | `2` | `SCK` | `I2C_SCL` | I2C clock. |
| `U5` | `3`, `8`, `9` | `VSS` | `GND` | Pressure sensor grounds. |
| `U5` | `4` | `SDI` | `I2C_SDA` | I2C data. |
| `U5` | `5` | `SDO` | `GND` | I2C address strap for address `0x46`. |
| `U5` | `6` | `CSB` | `+3V3` | I2C mode strap. |
| `U5` | `7` | `INT` | `BMP581_1_INT` | Interrupt output to `U4.4` / `IO4`. |
| `U5` | `10` | `VDD` | `+3V3` | First pressure sensor core supply. Decouple with `C12`. |
| `U6` | `1` | `VDDIO` | `+3V3` | Second pressure sensor I/O supply. Decouple with `C16`. |
| `U6` | `2` | `SCK` | `I2C_SCL` | I2C clock. |
| `U6` | `3`, `8`, `9` | `VSS` | `GND` | Pressure sensor grounds. |
| `U6` | `4` | `SDI` | `I2C_SDA` | I2C data. |
| `U6` | `5` | `SDO` | `+3V3` | I2C address strap for address `0x47`. |
| `U6` | `6` | `CSB` | `+3V3` | I2C mode strap. |
| `U6` | `7` | `INT` | `BMP581_2_INT` | Interrupt output to `U4.9` / `IO16`. |
| `U6` | `10` | `VDD` | `+3V3` | Second pressure sensor core supply. Decouple with `C15`. |
| `U2` | `1` | `SDO` | `GND` | I2C address strap. |
| `U2` | `2`, `3`, `10`, `11` | `NC` | `NC` | Leave floating and mark no-connect. |
| `U2` | `4` | `INT1` | `BMI323_INT1` | Interrupt output to `U4.9`. |
| `U2` | `5` | `VDDIO` | `+3V3` | IMU I/O supply. Decouple with `C5`. |
| `U2` | `6` | `GNDIO` | `GND` | IMU I/O ground. |
| `U2` | `7` | `GND` | `GND` | IMU core ground. |
| `U2` | `8` | `VDD` | `+3V3` | IMU core supply. Decouple with `C6`. |
| `U2` | `9` | `INT2` | `BMI323_INT2` | Interrupt output to `U4.10`. |
| `U2` | `12` | `CSB` | `+3V3` | I2C mode strap. |
| `U2` | `13` | `SCX` | `I2C_SCL` | I2C clock. |
| `U2` | `14` | `SDX` | `I2C_SDA` | I2C data. |

### User Interface And Drivers

| Ref | Pin | Pin name | Connect to | Instruction |
| --- | --- | --- | --- | --- |
| `SW1` | `1`, `2` | `A` | `PWR_SW_N` | Button side connected to raw active-low power switch net. |
| `SW1` | `3`, `4` | `B` | `GND` | Button side connected to ground. |
| `SW2` | `1`, `2` | `A` | `BOOT_USER_BTN_N` | Hidden service BOOT button side connected to ESP32-S3 GPIO0 strap. |
| `SW2` | `3`, `4` | `B` | `GND` | BOOT button pulls GPIO0 low for ROM bootloader recovery entry. |
| `SW3` | `1`, `2` | `A` | `EN` | Hidden service RESET/RST button side connected to ESP32-S3 enable/reset net. |
| `SW3` | `3`, `4` | `B` | `GND` | RST button pulls `EN` low. |
| `BZ1` | `1` | `+` | `SYS` | Buzzer positive terminal. Keep current path local to `C3`. |
| `BZ1` | `2` | `-` | `BUZZER_NEG` | Buzzer switched return to `Q1.3`. |
| `Q1` | `1` | `G` | `BUZZER_GATE` | Gate drive from `R8`, pulldown by `R7`. |
| `Q1` | `2` | `S` | `GND` | Low-side switch source. |
| `Q1` | `3` | `D` | `BUZZER_NEG` | Low-side switch drain to buzzer negative terminal. |
| `Q2` | `1` | `G` | `BLE_LED_GATE` | Gate drive from `R4`, pulldown by `R3`. |
| `Q2` | `2` | `S` | `GND` | Low-side switch source. |
| `Q2` | `3` | `D` | `BLE_LED_K` | Low-side switch drain to blue BLE pairing LED cathode. |
| `Q3` | `1` | `G` | `PWR_HOLD_GATE` | Gate drive from the hardware hold node. |
| `Q3` | `2` | `S` | `GND` | Low-side switch source. |
| `Q3` | `3` | `D` | `CHG_SYSOFF` | Pulls BQ24075 `SYSOFF` low while the power latch is active. |
| `D2` | `1` | `K` | `PWR_SW_N` | Isolates the raw power switch node from the MCU button input. |
| `D2` | `2` | `A` | `PWR_BTN_N` | Lets `SW1` pull the MCU button input low when the board is on. |
| `D3` | `1` | `K` | `PWR_SW_N` | Lets `SW1` pull `BAT_SWITCH_GATE` low during power-on. |
| `D3` | `2` | `A` | `BAT_SWITCH_GATE` | Diode-isolated start path for `Q4` gate. |
| `D4` | `1` | `K` | `PWR_SW_N` | Lets `SW1` pull `CHG_SYSOFF` low during power-on. |
| `D4` | `2` | `A` | `CHG_SYSOFF` | Diode-isolated start path for BQ24075 `SYSOFF`. |
| `LED1` | `1` | `K` | `BLE_LED_K` | Blue BLE pairing LED cathode to `Q2.3`. |
| `LED1` | `2` | `A` | `BLE_LED_A` | Blue BLE pairing LED anode through `R5` to `SYS`. |
| `LED2` | `1` | `-` | `GND` | Always-on green power LED cathode. |
| `LED2` | `2` | `+` | `POWER_LED_A` | Always-on green power LED anode through `R20` to `+3V3`. |

### Resistors And Capacitors

| Ref | Pin 1 connects to | Pin 2 connects to | Instruction |
| --- | --- | --- | --- |
| `R9` | `CC1` | `GND` | USB-C CC1 sink pulldown. |
| `R10` | `CC2` | `GND` | USB-C CC2 sink pulldown. |
| `R15` | `CHG_TS` | `GND` | Charger TS fixed bias. |
| `R12` | `CHG_ISET` | `GND` | Charger current-set resistor. |
| `R11` | `CHG_ILIM` | `GND` | Charger input-current limit resistor. |
| `R14` | `CHG_TMR` | `GND` | Charger timer resistor. |
| `R13` | `nCHG` | `+3V3` | Pull-up for charger `nCHG`. |
| `R19` | `nPGOOD` | `+3V3` | Pull-up for charger `nPGOOD`. |
| `R16` | `EN` | `+3V3` | ESP32 enable pull-up. |
| `R6` | `BOOT_USER_BTN_N` | `+3V3` | ESP32 boot strap pull-up. |
| `R23` | `CHG_SYSOFF` | `BAT` | Pulls `SYSOFF` high after the switched battery rail is present. |
| `R24` | `PWR_HOLD_GATE` | `+3V3` | Pulls the latch gate high after `+3V3` starts, so bootloader mode stays powered without firmware. |
| `R25` | `PWR_HOLD` | `PWR_HOLD_GATE` | Power-hold MOSFET gate series resistor. |
| `R26` | `PWR_HOLD_GATE` | `GND` | Keeps `Q3`/`Q5` off while `+3V3` is absent. |
| `R27` | `PWR_BTN_N` | `+3V3` | Pull-up for the active-low power/user button input. |
| `R28` | `BAT_SWITCH_GATE` | `BAT_RAW` | Pulls the P-channel battery switch gate high so the raw battery is disconnected by default. |
| `R2` | `BAT` | `BAT_SENSE` | Battery divider top resistor. |
| `R1` | `BAT_SENSE` | `GND` | Battery divider bottom resistor. |
| `R22` | `USB_VBUS` | `USB_VBUS_SENSE` | USB VBUS divider top resistor. |
| `R21` | `USB_VBUS_SENSE` | `GND` | USB VBUS divider bottom resistor. |
| `R17` | `I2C_SCL` | `+3V3` | I2C SCL pull-up. |
| `R18` | `I2C_SDA` | `+3V3` | I2C SDA pull-up. |
| `R8` | `BUZZER_PWM` | `BUZZER_GATE` | Buzzer MOSFET gate series resistor. |
| `R7` | `BUZZER_GATE` | `GND` | Buzzer MOSFET gate pulldown. |
| `R5` | `SYS` | `BLE_LED_A` | Blue BLE pairing LED current limit resistor. |
| `R4` | `BLE_LED_PWM` | `BLE_LED_GATE` | BLE pairing LED MOSFET gate series resistor. |
| `R3` | `BLE_LED_GATE` | `GND` | BLE pairing LED MOSFET gate pulldown. |
| `R20` | `+3V3` | `POWER_LED_A` | Always-on green power LED current limit resistor. |
| `C14` | `USB_VBUS` | `GND` | USB input capacitor. |
| `C1` | `BAT` | `GND` | Switched battery bulk capacitor. |
| `C13` | `SYS` | `GND` | System rail bulk capacitor. |
| `C7` | `SYS` | `GND` | LDO input capacitor. |
| `C8` | `+3V3` | `GND` | LDO output capacitor. |
| `C9` | `+3V3` | `GND` | ESP32 local bulk capacitor. |
| `C10` | `+3V3` | `GND` | ESP32 high-frequency decoupling capacitor. |
| `C12` | `+3V3` | `GND` | `U5` BMP581 VDD decoupling capacitor. |
| `C11` | `+3V3` | `GND` | `U5` BMP581 VDDIO decoupling capacitor. |
| `C15` | `+3V3` | `GND` | `U6` BMP581 VDD decoupling capacitor. |
| `C16` | `+3V3` | `GND` | `U6` BMP581 VDDIO decoupling capacitor. |
| `C6` | `+3V3` | `GND` | BMI323 VDD decoupling capacitor. |
| `C5` | `+3V3` | `GND` | BMI323 VDDIO decoupling capacitor. |
| `C3` | `SYS` | `GND` | Local buzzer bulk capacitor. |
| `C4` | `EN` | `GND` | ESP32 enable/reset capacitor. |
| `C2` | `BAT_SENSE` | `GND` | Battery ADC filter capacitor. |

## Connection And Layout Constraints

- Do not route USB data directly to the MCU before `D1`; the ESD device must be
  first in line after the connector.
- Keep `USB_OTG_DP` and `USB_OTG_DM` short, parallel, and length-similar. Avoid
  stubs around the ESD part.
- Keep `USB_VBUS`, `BAT`, and `SYS` wider than normal signal nets. These nets
  carry charging, regulator, and buzzer current.
- Do not feed ESP32 GPIO pull-ups from `SYS`; use `+3V3` only.
- Keep `C7` and `C8` tight to `U3`; moving them away can make the LDO unstable.
- Keep each 100 nF sensor capacitor tight to its target sensor pin. Do not group
  all capacitors in one corner of the board.
- Place `U4` so its U.FL/I-PEX MHF1 connector can be reached and the antenna
  coax can be strain-relieved. Keep the selected off-board antenna away from
  battery metal, buzzer metal, enclosure metal, and the user's body as much as
  the enclosure allows.
- Keep `U5` and `U6` away from heat sources, airflow from the buzzer, adhesive
  stress, and board edges that flex. Pressure sensors are sensitive to thermal
  and mechanical disturbance.
- Keep `U2` near the mechanical center of the board if orientation/acceleration
  data matters. Record final axis orientation in firmware.
- Keep `BZ1`, `Q1`, `R8`, `R7`, and `C3` together. The buzzer switching loop
  should not run under `U5`, `U6`, `U2`, or the I2C pull-ups.
- `SW1`, `D2`, `D3`, `D4`, `Q3`, `Q4`, `Q5`, `R23`, `R24`, `R26`, and `R28`
  form the hard-off latch. Keep `CHG_SYSOFF` and `BAT_SWITCH_GATE` short and
  away from noisy switching nodes.
- Firmware must leave `PWR_HOLD` high-Z/high for normal operation and drive it
  low only when intentionally shutting down from battery power.
- Firmware must use `USB_VBUS_SENSE` and `PWR_BTN_N` to keep USB attach from an
  off state in USB-attached idle mode until the user presses `POWER` or a
  supported start command is received.
- `SW2` and `SW3` provide hidden service ESP32-S3 ROM bootloader recovery
  without debug pads. PCB/enclosure access should be pinhole/service-only and
  labeled `BOOT` and `RST`.
- `J1` polarity must be checked against the intended LiPo connector and pack
  wiring. JST PH-compatible parts are often assembled with opposite cable
  conventions.
- The local footprints for `J1`, `BZ1`, `Q1`, `Q2`, `Q3`, `Q4`, `Q5`,
  `D2`-`D4`, and `SW1`-`SW3` should be checked against manufacturer
  land-pattern drawings before production.

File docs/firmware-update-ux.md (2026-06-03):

# FlySys Firmware Update UX

Updated: 2026-06-03

Normal firmware update is handled by application firmware. The hidden physical
BOOT and RESET controls are retained only as a recovery fallback when the
application updater is unavailable or a broken image cannot boot.

## User-Facing Update Path

Primary update entry is software-controlled while USB or another supported link
is connected. The firmware implementation may use USB MSC drag-and-drop, a USB
CDC update tool, BLE DFU, or OTA, but it must validate the new image before
activating it.

Use ESP-IDF OTA partitions with rollback. After rebooting into a new image,
firmware must mark the image valid only after the normal boot checks pass. If
the new image fails those checks or cannot confirm itself, rollback should return
the device to the previous working image.

## USB-Attached Idle Mode

USB-C attach is allowed to power the ESP32-S3 electrically. Firmware must decide
whether the user asked for the vario application to run.

At boot:

1. Read `USB_VBUS_SENSE`.
2. Read the persisted/current user power-intent state.
3. If USB is present and the user has not pressed `POWER`, enter
   USB-attached idle mode.
4. If `POWER` has been pressed, record user intent and start normal mode.

In USB-attached idle mode, do not start:

- Vario sensing/filtering.
- BLE advertising or normal BLE telemetry.
- Buzzer output.
- Flight logging or log rotation.
- Any normal flight behavior.

Allowed idle functions are limited to charging/status indication, the firmware
update endpoint, and an optional command that records user intent and starts
normal mode.

## Hidden Recovery Controls

Keep the physical recovery controls on the PCB but place them behind service
pinholes or another non-user-facing access path:

| Control | Net | Electrical behavior | PCB/service label |
| --- | --- | --- | --- |
| BOOT | `BOOT_USER_BTN_N` / ESP32-S3 `GPIO0` | Momentary short to `GND`; `R6` pulls up to `+3V3` | `BOOT` |
| RESET | `EN` | Momentary short to `GND`; `R16` pulls up to `+3V3`, `C4` provides 100 nF reset RC | `RST` |

Document these controls as recovery-only in user and service material. They are
not the normal firmware update workflow.

## Recovery Sequence

1. Connect USB-C.
2. Hold hidden `BOOT`.
3. Press and release hidden `RST`.
4. Release `BOOT`.
5. Run the ESP32-S3 flashing/recovery tool against the native USB ROM
   bootloader.

If a service setup must keep the board powered from battery before USB is
attached, press `POWER` first to latch the board; recovery flashing still
requires USB.

## Verification

- USB attach from off state: ESP32-S3 may power up, but firmware remains in
  USB-attached idle mode. Vario sensing, buzzer, BLE normal operation, and
  logging stay inactive.
- Start normal mode: with USB connected, press `POWER`; firmware exits idle mode
  and starts the main application.
- Software update: update through the selected firmware endpoint; verify image
  validation, reboot, and rollback behavior.
- Physical recovery: hold `BOOT`, tap `RST`, release `BOOT`; confirm the host
  detects the ESP32-S3 native USB ROM bootloader and flashing works.
- Failure fallback: install intentionally broken application firmware and verify
  hidden `BOOT` + `RST` recovery still works.

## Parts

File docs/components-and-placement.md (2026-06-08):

# FlySys KiCad Components and Placement

Updated: 2026-06-08

The KiCad schematic is in `kicad/flysys_vario.kicad_sch`. It uses the generated
local symbol library `kicad/flysys_symbols.kicad_sym` and footprint libraries
from `parts/`.

The DigiKey purchasing BOM is generated at
`kicad/flysys_vario_digikey_bom.csv`. A readable version is in
`docs/digikey-bom.md`. `ANT1` in that BOM is the off-board antenna for the
ESP32-S3-WROOM-1U module connector and has no PCB footprint. Debug pads are not
fitted in this design; normal firmware update is software-first, and ESP32-S3
ROM bootloader entry is a hidden service fallback through the USB connector plus
`BOOT`/`RST` buttons.

The Atopile/LCSC picked component set is documented separately in
`docs/lcsc-bom.md`. The full text description of the schematic, capacitor
roles, and wiring/layout constraints is in `docs/schematic-description.md`.
The firmware update and USB-attached idle UX is in
`docs/firmware-update-ux.md`.

Regenerate and verify the schematic with:

```sh
python3 tools/generate_kicad_schematic.py
snap run kicad.kicad-cli sch export netlist --format kicadsexpr --output build/kicad/flysys_vario.net kicad/flysys_vario.kicad_sch
snap run kicad.kicad-cli sch erc --format json --output build/kicad/flysys_vario_erc.json kicad/flysys_vario.kicad_sch
```

The component positions below describe intended physical placement for the PCB
layout review. They are not a claim that the KiCad PCB has been placed or
routed.

## Main Components

| Ref | Source instance | Component | Role | Placement intent |
| --- | --- | --- | --- | --- |
| `USB1` | `usb` | `USB4105-GF-A` USB-C receptacle | USB 2.0 device, charging input, flashing/log/config access | On board edge. Keep `D+`/`D-` short into `D1`; keep CC resistors next to connector. |
| `D1` | `usb_esd` | `USBLC6-2SC6Y` | Automotive/AEC-Q101 USB ESD protection | Between `USB1` and `U4`, close to `USB1`, before the USB pair enters the board. Same SOT-23-6L placement intent as the previous part. |
| `U1` | `charger` | `BQ24075RGTR` | LiPo charger and power-path management | Near USB VBUS and battery connector. Keep `IN`, `BAT`, `OUT`, and thermal ground paths short and wide. |
| `U3` | `ldo_3v3` | `TLV75533PDBVR` | 3.3 V regulator from `SYS` | Near `U1` and the `+3V3` loads. Keep input/output caps tight to pins. |
| `U4` | `mcu` | `ESP32-S3-WROOM-1U-N8` | BLE, USB device, application MCU with U.FL/I-PEX MHF1 antenna connector | Edge or accessible area so the off-board antenna cable can be attached and strain-relieved. Keep the antenna/cable away from metal and noisy power paths. |
| `ANT1` | BOM-only | `ANTX200P001B24003` | Off-board 2.4 GHz adhesive antenna | DigiKey order item only. It plugs into the module U.FL/I-PEX MHF1 connector and is not placed as a PCB footprint. |
| `U5` | `pressure_1` | `BMP581` | Pressure sensor for altitude/vario, I2C address `0x46` | Near pressure vent, away from heat, adhesive, board flex, and buzzer airflow. |
| `U6` | `pressure_2` | `BMP581` | Redundant/secondary pressure sensor, I2C address `0x47` | Near the same pressure environment as `U5`; keep both sensors away from heat gradients and direct buzzer airflow. |
| `U2` | `imu` | `BMI323` | 6-axis accelerometer/gyro | Near board center on mechanically stable PCB area. Document final axis orientation in firmware. |
| `J1` | `battery` | `S2B-PH-SM4-TB` | 2-pin LiPo connector | Near charger `BAT` pins. Confirm protected pack polarity before ordering/build. |
| `BZ1` | `buzzer` | `CSS-J4D20-SMT-TR` | Loud firmware-driven vario tone output | Lower/right side near acoustic outlet. Keep buzzer current loop local to `BZ1`, `Q1`, and `C3`. |
| `Q1` | `q_buzzer` | `AO3400A` | Low-side MOSFET for buzzer PWM | Next to buzzer return pad. Keep drain loop compact. |
| `Q2` | `q_ble_led` | `AO3400A` | Low-side MOSFET for blue BLE pairing LED | Near `LED1`/`R5`. Needed because blue LED is powered from `SYS`. |
| `Q3` | `q_sysoff` | `AO3400A` | Low-side MOSFET that latches BQ24075 `SYSOFF` low | Near `U1`/`SYSOFF` control resistors. Keep `CHG_SYSOFF` compact and quiet. |
| `Q4` | `q_bat_switch` | `DMP3098L` | P-channel high-side battery hard-off switch from `BAT_RAW` to `BAT` | Between `J1` and `U1 BAT`. Keep the switched battery path short and wide. |
| `Q5` | `q_bat_gate` | `AO3400A` | Low-side MOSFET that holds `Q4` gate low while power is latched | Near `Q4` gate and `R28`. |
| `D2`, `D3`, `D4` | power-start diodes | `1N4148W` | Diode isolation from raw power button to MCU input, `BAT_SWITCH_GATE`, and `CHG_SYSOFF` | Near `SW1` and the power latch nets. |
| `SW1` | `user_button` | `KMR211NG LFS` | Active-low power/user button | Accessible edge area. Pressing it starts the board from battery hard-off and is read by the MCU through `D2`; firmware also uses it to leave USB-attached idle mode. |
| `SW2` | `boot_button` | `KMR211NG LFS` | ESP32-S3 BOOT recovery button | Hidden service/pinhole access only. Label on PCB as `BOOT`; hold while tapping `RST` to enter ROM bootloader recovery. |
| `SW3` | `reset_button` | `KMR211NG LFS` | ESP32-S3 RESET recovery button | Hidden service/pinhole access only. Label on PCB as `RST`; use with `BOOT` for ROM bootloader recovery. |
| `LED2` | `power_led` | `LTST-C190GKT` green LED | Always-on `+3V3` power indicator | Lower edge where visible; series resistor `R20` next to it. |
| `LED1` | `ble_led` | `LTST-C190TBKT` blue LED | Firmware BLE pairing/advertising indicator | Lower/right visible edge; driven through `Q2`. Firmware should keep it off outside pairing/advertising mode. |

## Capacitors

| Ref | Source instance | Value | Connected nets | Purpose and placement |
| --- | --- | --- | --- | --- |
| `C14` | `c_vbus_in` | 1 uF | `USB_VBUS` to `GND` | USB input bulk/decoupling. Place close to `USB1`/`U1 IN`. |
| `C13` | `c_sys_bulk` | 10 uF | `SYS` to `GND` | Charger system rail bulk. Place close to `U1 OUT`; helps `U3` and buzzer transients. |
| `C1` | `c_bat_bulk` | 10 uF | `BAT` to `GND` | Switched battery rail bulk. Place near `Q4` drain and `U1 BAT`. |
| `C7` | `c_ldo_in` | 1 uF | `SYS` to `GND` | LDO input capacitor. Place at `U3 IN/GND`. |
| `C8` | `c_ldo_out` | 1 uF | `+3V3` to `GND` | LDO output capacitor. Place at `U3 OUT/GND`. |
| `C9` | `c_mcu_bulk` | 10 uF | `+3V3` to `GND` | ESP32-S3 local bulk for RF/current peaks. Place close to `U4 3V3`. |
| `C10` | `c_mcu_decoup` | 100 nF | `+3V3` to `GND` | ESP32-S3 high-frequency decoupling. Place close to `U4 3V3`. |
| `C12` | `c_pressure1_vdd` | 100 nF | `BMP581 U5 VDD` to `GND` | First pressure sensor core decoupling. Place next to `U5`. |
| `C11` | `c_pressure1_vddio` | 100 nF | `BMP581 U5 VDDIO` to `GND` | First pressure sensor I/O decoupling. Place next to `U5`. |
| `C15` | `c_pressure2_vdd` | 100 nF | `BMP581 U6 VDD` to `GND` | Second pressure sensor core decoupling. Place next to `U6`. |
| `C16` | `c_pressure2_vddio` | 100 nF | `BMP581 U6 VDDIO` to `GND` | Second pressure sensor I/O decoupling. Place next to `U6`. |
| `C6` | `c_imu_vdd` | 100 nF | `BMI323 VDD` to `GND` | IMU core decoupling. Place next to `U2`. |
| `C5` | `c_imu_vddio` | 100 nF | `BMI323 VDDIO` to `GND` | IMU I/O decoupling. Place next to `U2`. |
| `C3` | `c_buzzer_bulk` | 10 uF | `SYS` to `GND` | Local buzzer supply reservoir. Place close to `BZ1`/`Q1` to keep current loop local. |
| `C4` | `c_en` | 100 nF | `EN` to `GND` | ESP32-S3 reset/enable RC cap. Place close to `U4 EN`. |
| `C2` | `c_bat_sense` | 100 nF | `BAT_SENSE` to `GND` | ADC filter for battery divider. Place near MCU ADC pin and divider midpoint. |

## Resistors

| Ref | Source instance | Value | Purpose and placement |
| --- | --- | --- | --- |
| `R9` | `r_cc1` | 5.1 k | USB-C `CC1` pull-down. Place close to `USB1`. |
| `R10` | `r_cc2` | 5.1 k | USB-C `CC2` pull-down. Place close to `USB1`. |
| `R15` | `r_chg_ts` | 10 k | Charger TS bias for baseline no-thermistor setup. Place close to `U1 TS`; revisit if using pack thermistor. |
| `R12` | `r_chg_iset` | 2 k | BQ24075 charge-current set resistor. Place close to `U1 ISET`. |
| `R11` | `r_chg_ilim` | 1.1 k | BQ24075 input current-limit set resistor. Place close to `U1 ILIM`. |
| `R14` | `r_chg_tmr` | 47 k | BQ24075 timer set resistor. Place close to `U1 TMR`. |
| `R13` | `r_chg_pullup` | 10 k | Pull-up for charger `nCHG` status into MCU. Place near `U1`/routing to `U4`. |
| `R19` | `r_pgood_pullup` | 10 k | Pull-up for charger `nPGOOD` status into MCU. Place near `U1`/routing to `U4`. |
| `R16` | `r_en_pullup` | 10 k | ESP32-S3 `EN` pull-up. Place close to `U4 EN`; keep near `C4`. |
| `R6` | `r_boot_pullup` | 10 k | ESP32-S3 `IO0`/BOOT pull-up. Place near `U4`/`SW2`. |
| `R23` | `r_sysoff_pullup` | 1 M | Pull-up from `CHG_SYSOFF` to switched `BAT`. Place near `U1 SYSOFF`. |
| `R24` | `r_pwr_hold_gate_pu` | 100 k | Pull-up from `PWR_HOLD_GATE` to `+3V3` so power latches even in ROM bootloader. Place near `Q3`/`Q5`. |
| `R25` | `r_pwr_hold_gate` | 100 ohm | Series resistor from MCU `PWR_HOLD` to the latch gate. Place near `U4`/`Q3` route. |
| `R26` | `r_pwr_hold_gate_pd` | 1 M | Latch-gate pulldown while `+3V3` is absent. Place near `Q3`/`Q5`. |
| `R27` | `r_pwr_btn_pullup` | 4.7 k | Pull-up for active-low `PWR_BTN_N` button input. Place near `U4`/`SW1`. |
| `R28` | `r_bat_switch_gate_pu` | 1 M | Pull-up from `BAT_SWITCH_GATE` to `BAT_RAW` for true battery disconnect by default. Place near `Q4`. |
| `R2` | `r_bat_sense_top` | 1 M | Top of battery voltage divider from `BAT` to `BAT_SENSE`. Place near `R1`/`C2`; keep divider node quiet. |
| `R1` | `r_bat_sense_bottom` | 1 M | Bottom of battery voltage divider from `BAT_SENSE` to `GND`. Place near `R2`/`C2`. |
| `R22` | `r_vbus_sense_top` | 1 M | Top of USB VBUS sense divider. Place near `R21` and route to MCU sense input. |
| `R21` | `r_vbus_sense_bottom` | 330 k | Bottom of USB VBUS sense divider. Place near `R22`. |
| `R17` | `r_i2c_scl_pullup` | 4.7 k | I2C SCL pull-up to `+3V3`. Place between MCU and sensors; keep away from noisy buzzer loop. |
| `R18` | `r_i2c_sda_pullup` | 4.7 k | I2C SDA pull-up to `+3V3`. Place next to `R17`. |
| `R8` | `r_buzzer_gate` | 100 ohm | Series gate resistor from ESP32 PWM to `Q1`. Place at `Q1` gate. |
| `R7` | `r_buzzer_gate_pd` | 100 k | `Q1` gate pulldown so buzzer stays off at reset. Place at `Q1` gate/source. |
| `R20` | `r_power_led` | 1 k | Always-on green power LED current limit from `+3V3`. Place next to `LED2`. |
| `R5` | `r_ble_led` | 1 k | Blue BLE pairing LED current limit from `SYS`. Place next to `LED1`/`Q2`. |
| `R4` | `r_ble_gate` | 100 ohm | Series gate resistor from ESP32 GPIO to `Q2`. Place at `Q2` gate. |
| `R3` | `r_ble_gate_pd` | 100 k | `Q2` gate pulldown so the BLE pairing LED stays off at reset. Place at `Q2` gate/source. |

## Routing Constraints for PCB Layout Review

See `docs/schematic-description.md` for the full text version of the schematic
and detailed connection constraints.

- USB `D+`/`D-` must route from `USB1` through `D1` before going to `U4 GPIO20/GPIO19`. Keep this pair short and parallel in the final layout review.
- `SW2` and `SW3` should be reachable only through service access or pinholes, not as normal exposed user controls. Add `BOOT` and `RST` PCB/service labels.
- `USB_VBUS`, `BAT`, and `SYS` are routed wider than logic nets. These carry charger, regulator, and buzzer current.
- `+3V3` fans out from `U3` to `U4`, `U5`, `U6`, `U2`, pull-ups, and the always-on green power LED.
- `U5`, `U6`, and `U2` decoupling capacitors are placed adjacent to their devices rather than grouped with generic capacitors.
- `U5 SDO` is tied to `GND` for I2C address `0x46`; `U6 SDO` is tied to `+3V3` for address `0x47`. Both `CSB` pins are tied to `+3V3` for I2C mode.
- `BMP581_1_INT` and `BMP581_2_INT` route independently to `U4` so firmware can distinguish the two barometers.
- The selected antenna is 4.4 dBi. Treat RF/EMC approval as an open item because Espressif's certified external antenna guidance recommends a lower maximum gain.
- `BZ1`, `Q1`, `R8`, `R7`, and `C3` are grouped together to keep the buzzer switching current local.
- `U1`, `Q3`, `Q4`, `Q5`, `D2`-`D4`, `R23`, `R24`, `R26`, and `R28` should keep the hard-off latch short and away from the buzzer gate and USB data routing.

## Current Limitations

The local footprints for `J1`, `BZ1`, `Q1`, `Q2`, `Q3`, `Q4`, `Q5`, `D2`-`D4`, `SW1`-`SW3`, and `U4` are draft local footprints. Before production, verify each against manufacturer land-pattern drawings, RF connector access, and enclosure mechanics.

Atopile 0.15.7 currently supports only LCSC in its built-in `has_part_picked`
BOM path. For DigiKey-only ordering, use the generated DigiKey BOM above. For
the current Atopile-picked LCSC subset, use `docs/lcsc-bom.md`.

The KiCad schematic is verified by ERC and netlist export, but the PCB placement and routing still need a separate KiCad layout pass.

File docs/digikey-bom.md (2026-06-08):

# FlySys DigiKey BOM

Updated: 2026-06-08

All purchased components in the KiCad schematic use DigiKey order lines. `ANT1` is an off-board antenna order line for the ESP32-S3-WROOM-1U module connector and has no PCB footprint. Debug pads are not fitted; normal firmware update is software-first, and ESP32-S3 bootloader recovery uses USB plus hidden BOOT and RST service buttons.

| References | Qty | Value | Manufacturer | MPN | DigiKey PN | Description |
| --- | ---: | --- | --- | --- | --- | --- |
| Q1, Q2, Q3, Q5 | 4 | AO3400A | Alpha & Omega Semiconductor Inc. | AO3400A | [785-1000-1-ND](https://www.digikey.si/en/products/detail/alpha-omega-semiconductor-inc/AO3400A/1855772) | N-channel MOSFET, SOT-23 |
| U2 | 1 | BMI323 | Bosch Sensortec | BMI323 | [828-BMI323CT-ND](https://www.digikey.si/en/products/detail/bosch-sensortec/BMI323/16719593) | 6-axis IMU |
| U5, U6 | 2 | BMP581 | Bosch Sensortec | BMP581 | [828-BMP581CT-ND](https://www.digikey.si/en/products/detail/bosch-sensortec/BMP581/16036134) | Barometric pressure sensor |
| SW1, SW2, SW3 | 3 | KMR211NG LFS | C&K | KMR211NG LFS | [CKN10243CT-ND](https://www.digikey.si/en/products/detail/c-k/KMR211NG-LFS/2176482) | Low-profile tactile switch |
| D2, D3, D4 | 3 | 1N4148W | Diodes Incorporated | 1N4148W-7-F | [1N4148W-FDICT-ND](https://www.digikey.si/en/products/detail/diodes-incorporated/1N4148W-7-F/815280) | Small-signal switching diode, SOD-123 |
| Q4 | 1 | DMP3098L | Diodes Incorporated | DMP3098L-7 | [DMP3098LDICT-ND](https://www.digikey.si/en/products/detail/diodes-incorporated/DMP3098L-7/1964699) | P-channel MOSFET, SOT-23 |
| U4 | 1 | ESP32-S3-WROOM-1U-N8 | Espressif Systems | ESP32-S3-WROOM-1U-N8 | [1965-ESP32-S3-WROOM-1U-N8CT-ND](https://www.digikey.si/en/products/detail/espressif-systems/ESP32-S3-WROOM-1U-N8/16162635) | ESP32-S3 module with U.FL/I-PEX MHF1 antenna connector and 8 MB flash |
| USB1 | 1 | USB4105-GF-A | GCT | USB4105-GF-A | [2073-USB4105-GF-ACT-ND](https://www.digikey.si/en/products/detail/gct/USB4105-GF-A/11198441) | USB-C receptacle, USB 2.0, right angle |
| J1 | 1 | S2B-PH-SM4-TB | JST Sales America Inc. | S2B-PH-SM4-TB | [455-S2B-PH-SM4-TBCT-ND](https://www.digikey.si/en/products/detail/jst-sales-america-inc/S2B-PH-SM4-TB/926655) | 2-pin JST PH side-entry SMT header |
| LED2 | 1 | LTST-C190GKT | Lite-On Inc. | LTST-C190GKT | [160-LTST-C190GKTCT-ND](https://www.digikey.si/en/products/detail/lite-on-inc/LTST-C190GKT/269255) | Green 0603 LED |
| LED1 | 1 | LTST-C190TBKT | Lite-On Inc. | LTST-C190TBKT | [160-1646-1-ND](https://www.digikey.si/en/products/detail/lite-on-inc/LTST-C190TBKT/388529) | Blue 0603 LED |
| D1 | 1 | USBLC6-2SC6Y | STMicroelectronics | USBLC6-2SC6Y | [497-11882-1-ND](https://www.digikey.si/en/products/detail/stmicroelectronics/USBLC6-2SC6Y/2819177) | Automotive USB ESD protection diode array, SOT-23-6 |
| BZ1 | 1 | CSS-J4D20-SMT-TR | Same Sky (Formerly CUI Devices) | CSS-J4D20-SMT-TR | [102-1198-1-ND](https://www.digikey.si/en/products/detail/same-sky-formerly-cui-devices/CSS-J4D20-SMT-TR/504819) | Externally driven magnetic buzzer |
| C7, C8, C14 | 3 | 1uF | Samsung Electro-Mechanics | CL10A105KB8NNNC | [1276-1860-1-ND](https://www.digikey.si/en/products/detail/samsung-electro-mechanics/CL10A105KB8NNNC/3887518) | 1 uF, 50 V, X5R, 0603 capacitor |
| C1, C3, C9, C13 | 4 | 10uF | Samsung Electro-Mechanics | CL10A106KP8NNNC | [1276-1192-1-ND](https://www.digikey.si/en/products/detail/samsung-electro-mechanics/CL10A106KP8NNNC/3886850) | 10 uF, 10 V, X5R, 0603 capacitor |
| U1 | 1 | BQ24075RGTR | Texas Instruments | BQ24075RGTR | [296-38874-1-ND](https://www.digikey.si/en/products/detail/texas-instruments/BQ24075RGTR/2047273) | Li-ion charger and power-path controller |
| U3 | 1 | TLV75533PDBVR | Texas Instruments | TLV75533PDBVR | [296-50411-1-ND](https://www.digikey.si/en/products/detail/texas-instruments/TLV75533PDBVR/9356541) | 3.3 V 500 mA LDO regulator |
| C2, C4, C5, C6, C10, C11, C12, C15, C16 | 9 | 100nF | YAGEO | CC0603KRX7R9BB104 | [311-1344-1-ND](https://www.digikey.si/en/products/detail/yageo/CC0603KRX7R9BB104/2103082) | 100 nF, 50 V, X7R, 0603 capacitor |
| R3, R7, R24 | 3 | 100k | YAGEO | RC0603FR-07100KL | [311-100KHRCT-ND](https://www.digikey.si/en/products/detail/yageo/RC0603FR-07100KL/726889) | 100 kohm, 1%, 0.1 W, 0603 resistor |
| R4, R8, R25 | 3 | 100R | YAGEO | RC0603FR-07100RL | [311-100HRCT-ND](https://www.digikey.si/en/products/detail/yageo/RC0603FR-07100RL/726888) | 100 ohm, 1%, 0.1 W, 0603 resistor |
| R6, R13, R15, R16, R19 | 5 | 10k | YAGEO | RC0603FR-0710KL | [311-10.0KHRCT-ND](https://www.digikey.si/en/products/detail/yageo/RC0603FR-0710KL/726880) | 10 kohm, 1%, 0.1 W, 0603 resistor |
| R11 | 1 | 1.1k | YAGEO | RC0603FR-071K1L | [311-1.10KHRCT-ND](https://www.digikey.si/en/products/detail/yageo/RC0603FR-071K1L/726848) | 1.1 kohm, 1%, 0.1 W, 0603 resistor |
| R5, R20 | 2 | 1k | YAGEO | RC0603FR-071KL | [311-1.00KHRCT-ND](https://www.digikey.si/en/products/detail/yageo/RC0603FR-071KL/726843) | 1 kohm, 1%, 0.1 W, 0603 resistor |
| R1, R2, R22, R23, R26, R28 | 6 | 1M | YAGEO | RC0603FR-071ML | [311-1.00MHRCT-ND](https://www.digikey.si/en/products/detail/yageo/RC0603FR-071ML/729791) | 1 Mohm, 1%, 0.1 W, 0603 resistor |
| R12 | 1 | 2k | YAGEO | RC0603FR-072KL | [311-2.00KHRCT-ND](https://www.digikey.si/en/products/detail/yageo/RC0603FR-072KL/727009) | 2 kohm, 1%, 0.1 W, 0603 resistor |
| R21 | 1 | 330k | YAGEO | RC0603FR-07330KL | [311-330KHRCT-ND](https://www.digikey.si/en/products/detail/yageo/RC0603FR-07330KL/727163) | 330 kohm, 1%, 0.1 W, 0603 resistor |
| R14 | 1 | 47k | YAGEO | RC0603FR-0747KL | [311-47.0KHRCT-ND](https://www.digikey.si/en/products/detail/yageo/RC0603FR-0747KL/727253) | 47 kohm, 1%, 0.1 W, 0603 resistor |
| R17, R18, R27 | 3 | 4.7k | YAGEO | RC0603FR-074K7L | [311-4.70KHRCT-ND](https://www.digikey.si/en/products/detail/yageo/RC0603FR-074K7L/727212) | 4.7 kohm, 1%, 0.1 W, 0603 resistor |
| R9, R10 | 2 | 5.1k | YAGEO | RC0603FR-075K1L | [311-5.10KHRCT-ND](https://www.digikey.si/en/products/detail/yageo/RC0603FR-075K1L/727268) | 5.1 kohm, 1%, 0.1 W, 0603 resistor |
| ANT1 | 1 | ANTX200P001B24003 | Pulse Electronics | ANTX200P001B24003 | [311-1553-ND](https://www.digikey.si/en/products/detail/pulse-electronics/ANTX200P001B24003/3927174) | Off-board 2.4 GHz flat patch antenna, U.FL/I-PEX MHF1, adhesive mount; not a PCB footprint |

Note: Atopile 0.15.7 currently supports only LCSC in its built-in `has_part_picked` BOM path. The DigiKey BOM above is therefore generated by this project script and is the procurement source of truth.

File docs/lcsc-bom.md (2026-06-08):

# FlySys LCSC Component Set

Updated: 2026-06-08

This table lists the components that Atopile currently resolves through its
built-in LCSC picker path. It is generated from the active Atopile BOM at
`build/builds/default/default.bom.csv`.

The project also has parts that are not in this LCSC set: `D2`, `D3`, `D4`,
`Q1`, `Q2`, `Q3`, `Q4`, `Q5`, `U4`, `U5`, `U6`, `SW1`, `SW2`, `SW3`, `J1`,
`BZ1`, and off-board `ANT1` are handled in the DigiKey BOM. Debug pads are not
fitted.

| References | Qty | Value | Manufacturer | MPN | LCSC Part |
| --- | ---: | --- | --- | --- | --- |
| `C1`, `C3`, `C9`, `C13` | 4 | 10 uF, 10 V, X5R | Samsung Electro-Mechanics | `CL10A106KP8NNNC` | `C19702` |
| `C2`, `C4`, `C5`, `C6`, `C10`, `C11`, `C12`, `C15`, `C16` | 9 | 100 nF, 50 V, X7R | YAGEO | `CC0603KRX7R9BB104` | `C14663` |
| `C7`, `C8`, `C14` | 3 | 1 uF, 50 V, X5R | Samsung Electro-Mechanics | `CL10A105KB8NNNC` | `C15849` |
| `D1` | 1 | Automotive USB ESD protection, SOT-23-6L | STMicroelectronics | `USBLC6-2SC6Y` | `C2969755` |
| `LED1` | 1 | Blue 0603 LED | Lite-On | `LTST-C190TBKT` | `C125096` |
| `LED2` | 1 | Green 0603 LED | Lite-On | `LTST-C190GKT` | `C125093` |
| `R1`, `R2`, `R22`, `R23`, `R26`, `R28` | 6 | 1 Mohm, 1%, 0603 | UNI-ROYAL | `0603WAF1004T5E` | `C22935` |
| `R3`, `R7`, `R24` | 3 | 100 kohm, 1%, 0603 | UNI-ROYAL | `0603WAF1003T5E` | `C25803` |
| `R4`, `R8`, `R25` | 3 | 100 ohm, 1%, 0603 | UNI-ROYAL | `0603WAF1000T5E` | `C22775` |
| `R5`, `R20` | 2 | 1 kohm, 1%, 0603 | UNI-ROYAL | `0603WAF1001T5E` | `C21190` |
| `R6`, `R13`, `R15`, `R16`, `R19` | 5 | 10 kohm, 1%, 0603 | UNI-ROYAL | `0603WAF1002T5E` | `C25804` |
| `R9`, `R10` | 2 | 5.1 kohm, 1%, 0603 | UNI-ROYAL | `0603WAF5101T5E` | `C23186` |
| `R11` | 1 | 1.1 kohm, 1%, 0603 | UNI-ROYAL | `0603WAF1101T5E` | `C22764` |
| `R12` | 1 | 2 kohm, 1%, 0603 | UNI-ROYAL | `0603WAF2001T5E` | `C22975` |
| `R14` | 1 | 47 kohm, 1%, 0603 | UNI-ROYAL | `0603WAF4702T5E` | `C25819` |
| `R17`, `R18`, `R27` | 3 | 4.7 kohm, 1%, 0603 | UNI-ROYAL | `0603WAF4701T5E` | `C23162` |
| `R21` | 1 | 330 kohm, 1%, 0603 | UNI-ROYAL | `0603WAF3303T5E` | `C23137` |
| `U1` | 1 | LiPo charger and power-path controller | Texas Instruments | `BQ24075RGTR` | `C15464` |
| `U2` | 1 | 6-axis IMU | Bosch Sensortec | `BMI323` | `C5368700` |
| `U3` | 1 | 3.3 V LDO regulator | Texas Instruments | `TLV75533PDBVR` | `C404027` |
| `USB1` | 1 | USB-C receptacle | GCT | `USB4105-GF-A` | `C3020560` |

## Procurement Note

Use `docs/digikey-bom.md` or `kicad/flysys_vario_digikey_bom.csv` when the
order must be DigiKey-only. Use this LCSC table when checking what Atopile
currently knows how to pick through its built-in supplier flow.

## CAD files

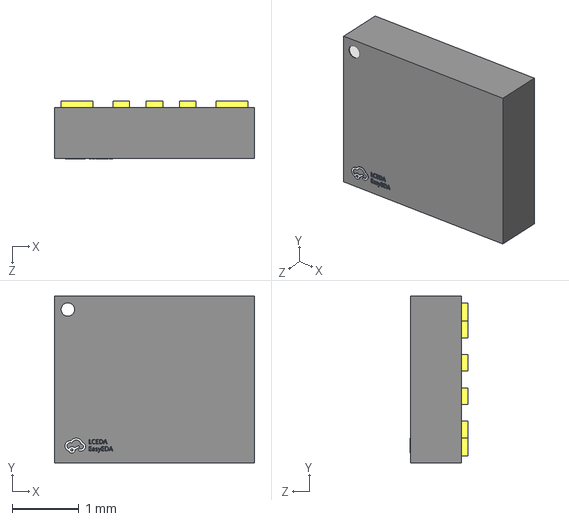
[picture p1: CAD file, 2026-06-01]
parts/Bosch_Sensortec_BMI323/LGA-14_L3.0-W2.5-P0.50-TL_QMI8658A.STEP
3.00 x 2.50 x 0.87 mm

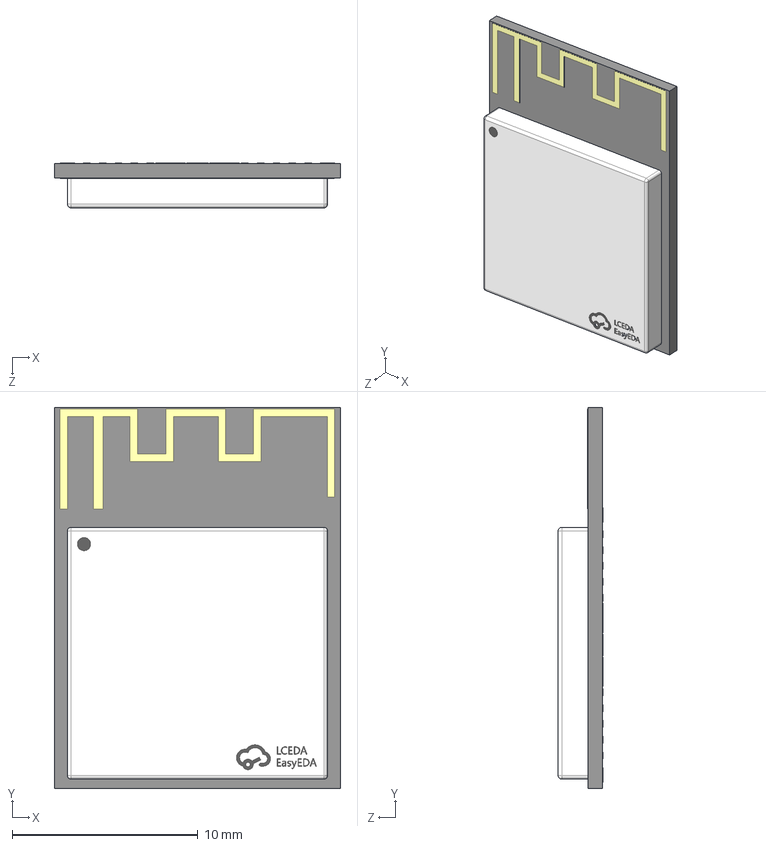
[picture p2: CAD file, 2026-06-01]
parts/Espressif_Systems_ESP32_S3_MINI_1_N8/BULETM-SMD_ESP32-S3-MINI-1-N8.step
15.4 x 20.5 x 2.43 mm

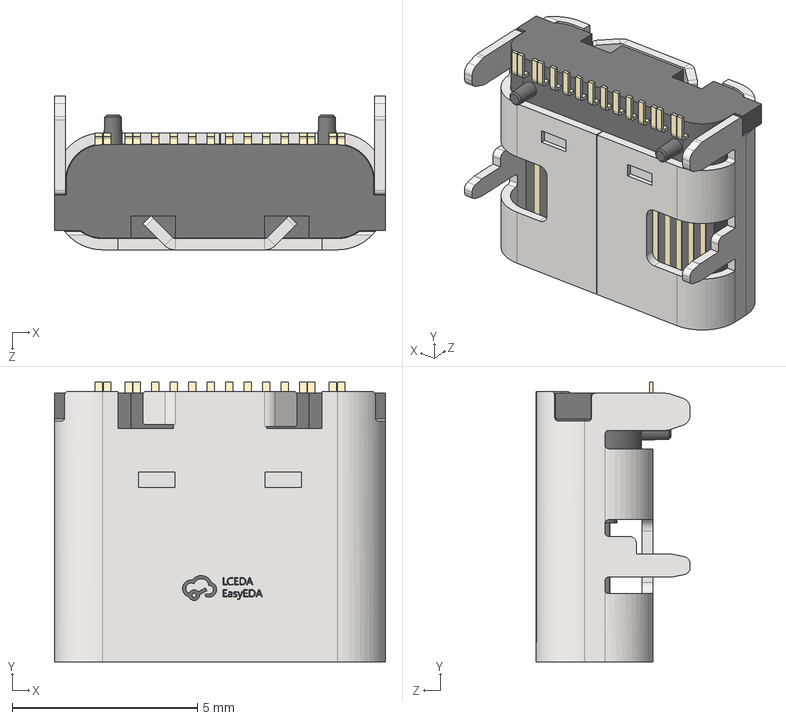
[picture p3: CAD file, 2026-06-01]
parts/GCT_USB4105_GF_A/TYPE-C-SMD_SBC-160S1A-20-S412.STEP
8.94 x 7.55 x 4.17 mm

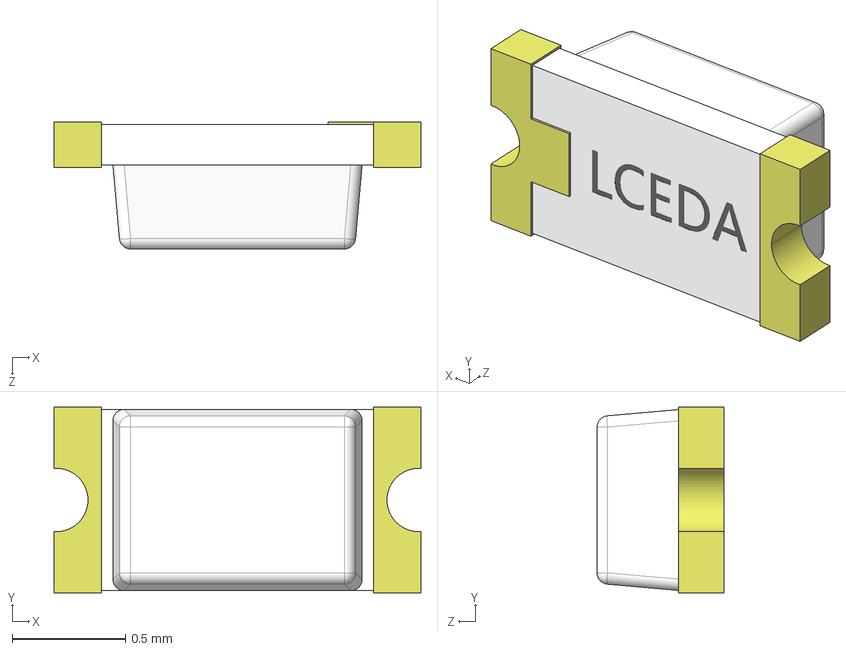
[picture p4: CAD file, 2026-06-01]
parts/Lite_On_LTST_C190GKT/LED0603-RD-YELLOW.STEP
1.62 x 0.82 x 0.56 mm

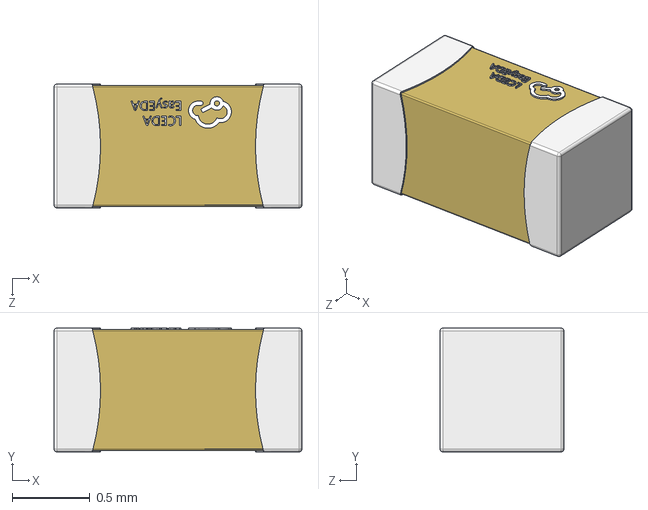
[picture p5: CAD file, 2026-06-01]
parts/Samsung_Electro_Mechanics_CL10A105KB8NNNC/C0603_L1.6-W0.8-H0.8.step
1.60 x 0.8 x 0.8 mm

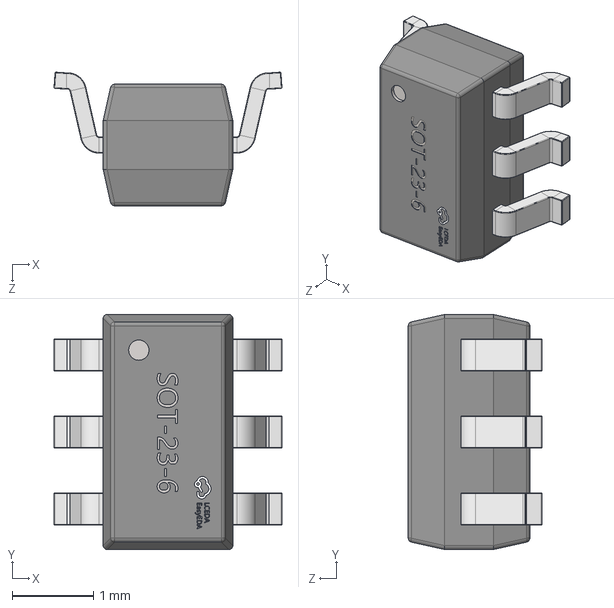
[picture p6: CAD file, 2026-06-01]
parts/STMicroelectronics_USBLC6_2SC6/SOT-23-6_L2.9-W1.6-H1.5-LS2.8-P0.95.step
2.81 x 2.90 x 1.65 mm

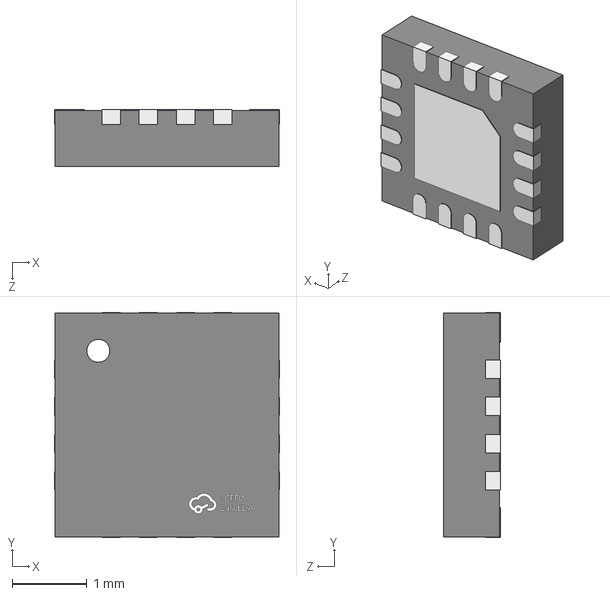
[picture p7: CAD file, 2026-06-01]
parts/Texas_Instruments_BQ24075RGTR/QFN-16_L3.0-W3.0-P0.50-EP1.7.STEP
3.02 x 3.02 x 0.76 mm

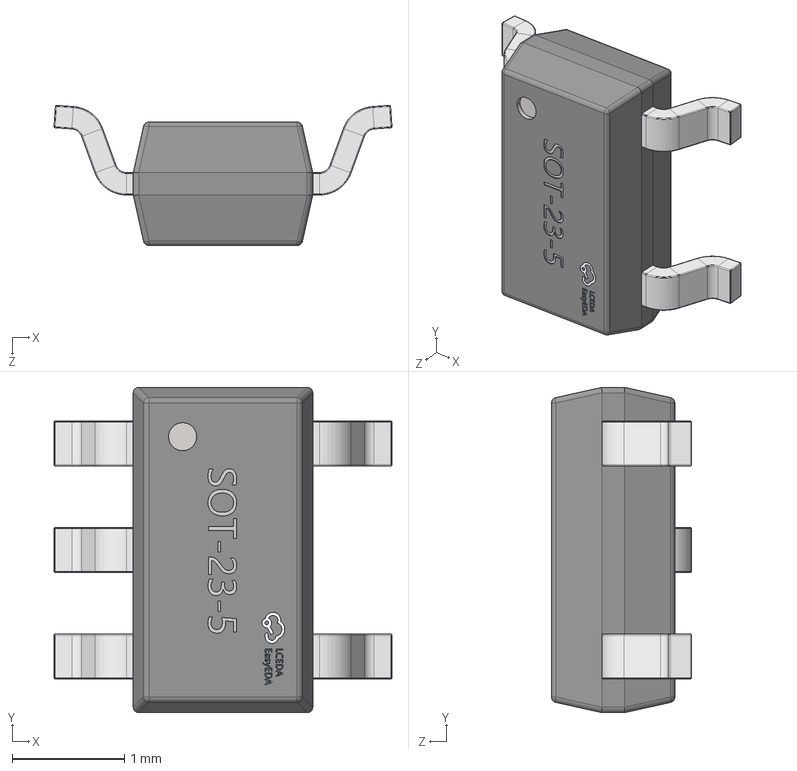
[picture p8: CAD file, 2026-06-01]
parts/Texas_Instruments_TLV75533PDBVR/SOT-23-5_L2.9-W1.6-H1.1-LS2.8-P0.95.step
3.01 x 2.90 x 1.25 mm

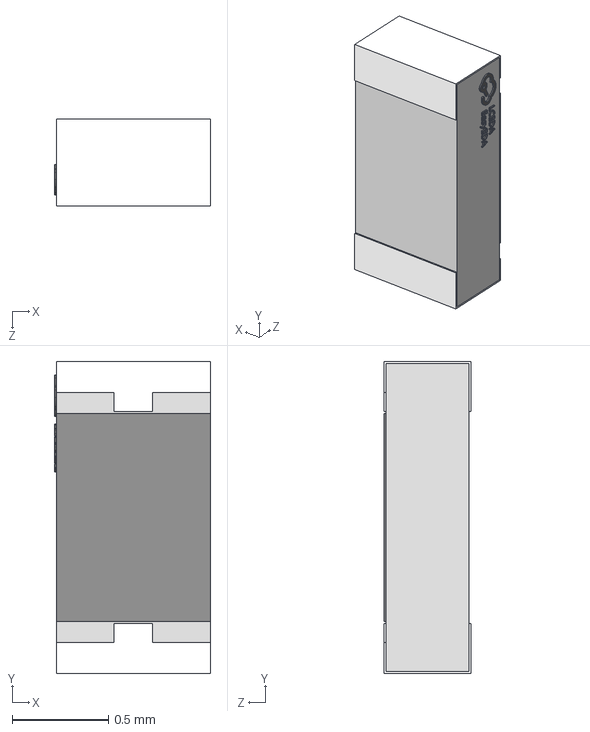
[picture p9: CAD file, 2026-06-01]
parts/UNI_ROYAL_0603WAF1000T5E/R0603.STEP
0.81 x 1.62 x 0.45 mm

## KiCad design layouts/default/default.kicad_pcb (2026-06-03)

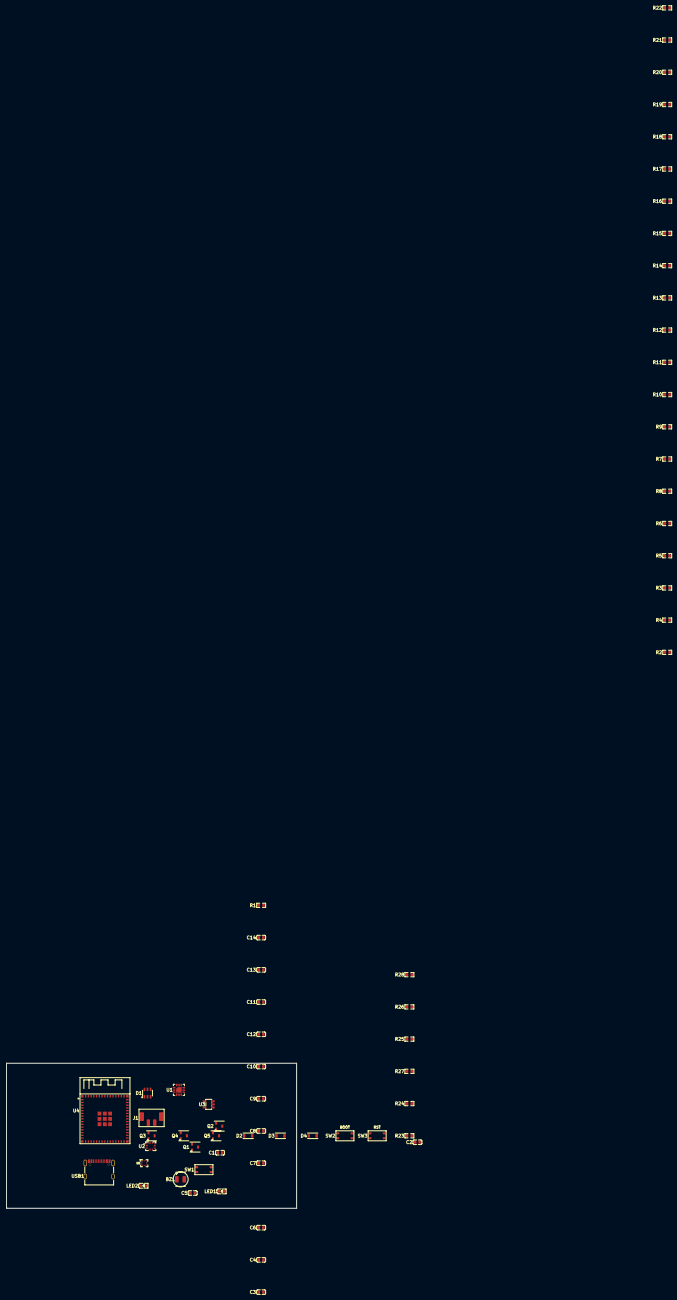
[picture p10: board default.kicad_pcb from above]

Board: 2 copper layers, 90.0 x 45.0 mm, 64 parts (0 on the bottom side), 41 nets, no tracks yet.

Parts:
BZ1: CSS-J4D20-SMT-TR
C1, C3, C9, C13: 10µF ±10%; C0603
C2, C4, C5, C6, C10, C11, C12: 100nF ±10%; C0603
C7, C8, C14: 1µF ±10%; C0603
D1: SOT-23-6_L2.9-W1.6-P0.95-LS2.8-BL
D2, D3, D4: 1N4148W
J1: S2B-PH-SM4-TB
LED1, LED2: LED0603-RD
Q1, Q2, Q3, Q5: AO3400A
Q4: DMP3098L
R1, R2, R22, R23, R25, R28: 1MΩ ±1%; R0603
R3, R7, R26: 100kΩ ±1%; R0603
R4, R8, R27: 100Ω ±1%; R0603
R5, R20: 1kΩ ±1%; R0603
R6, R13, R15, R16, R19: 10kΩ ±1%; R0603
R9, R10: 5.1kΩ ±1%; R0603
R11: 1.1kΩ ±1%; R0603
R12: 2kΩ ±1%; R0603
R14: 47kΩ ±1%; R0603
R17, R18, R24: 4.7kΩ ±1%; R0603
R21: 330kΩ ±1%; R0603
SW1: KMR211NG_LFS
SW2: KMR211NG_LFS_BOOT
SW3: KMR211NG_LFS_RST
U1: QFN-16_L3.0-W3.0-P0.50-TL-EP1.7
U2: LGA-14_L3.0-W2.5-P0.50-TL_QMI8658A
U3: SOT-23-5_L3.0-W1.7-P0.95-LS2.8-BR
U4: BULETM-SMD_ESP32-S3-MINI-1-N8
U5: BMP581_LGA10_2x2mm
USB1: TYPE-C-SMD_SBC-160S1A-20-S412

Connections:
4: U2.4, U4.9
10: U2.9, U4.10
14: R27.1, U4.14
21: R8.1, U4.21
22: R4.1, U4.22
A: LED1.2, R5.2
A5: R9.1, USB1.A5
B5: R10.1, USB1.B5
BAT_SENSE: C2.1, R1.1, R2.2, U4.5
BAT_SWITCH_GATE: D3.2, Q4.1, Q5.3, R23.1
BLE_LED_GATE: Q2.1, R3.1, R4.2
BOOT_USER_BTN_N: R6.1, SW2.1, SW2.2, U4.4
BUZZER_GATE: Q1.1, R7.1, R8.2
CHG_SYSOFF: D4.2, Q3.3, R28.1, U1.15
DRAIN: LED1.1, Q2.3
DRAIN-1: BZ1.2, Q1.3
EN: C4.1, R16.1, SW3.1, SW3.2, U4.45
GND: C1.2, C2.2, C3.2, C4.2, C5.2, C6.2, C7.2, C8.2, C9.2, C10.2, C11.2, C12.2, C13.2, C14.2, D1.2, J1.2, LED2.1, Q1.2, Q2.2, Q3.2, Q5.2, R1.2, R3.2, R7.2, R9.2, R10.2, R11.2, R12.2, R14.2, R15.2, R21.2, R25.2, SW1.3, SW1.4, SW2.3, SW2.4, SW3.3, SW3.4, U1.4, U1.6, U1.8, U1.17, U2.1, U2.6, U2.7, U3.2, U4.1, U4.2, U4.42, U4.43, U4.46, U4.47, U4.48, U4.49, U4.50, U4.51, U4.52, U4.53, U4.54, U4.55, U4.56, U4.57, U4.58, U4.59, U4.60, U4.GND, U5.3, U5.5, U5.8, U5.9, USB1.1, USB1.A1, USB1.A12, USB1.B1, USB1.B12
I2C_SCL: R17.1, U2.13, U4.12, U5.2
I2C_SDA: R18.1, U2.14, U4.13, U5.4
ILIM: R11.1, U1.12
INT: U4.8, U5.7
ISET: R12.1, U1.16
PWR_BTN_N: D2.2, R24.1, U4.11
PWR_HOLD_GATE: Q3.1, Q5.1, R25.1, R26.1, R27.2
PWR_SW_N: D2.1, D3.1, D4.1, SW1.1, SW1.2
TMR: R14.1, U1.14
TS: R15.1, U1.1
USB_DM_CONN: D1.3, USB1.A7, USB1.B7
USB_DP_CONN: D1.1, USB1.A6, USB1.B6
USB_OTG_DM: D1.4, U4.23
USB_OTG_DP: D1.6, U4.24
USB_VBUS_SENSE: R21.1, R22.2, U4.6
bat_raw-hv: J1.1, Q4.2, R23.2
c_pressure_vddio-power-hv: C5.1, C6.1, C8.1, C9.1, C10.1, C11.1, C12.1, R6.2, R13.2, R16.2, R17.2, R18.2, R19.2, R20.1, R24.2, R26.2, U2.5, U2.8, U2.12, U3.5, U4.3, U5.1, U5.6, U5.10
c_sys_bulk-power-hv: BZ1.1, C3.1, C7.1, C13.1, R5.1, U1.5, U1.10, U1.11, U3.1, U3.3
c_vbus_in-power-hv: C14.1, D1.5, R22.1, U1.13, USB1.A4, USB1.A9, USB1.B4, USB1.B9
hv: C1.1, Q4.3, R2.1, R28.2, U1.2, U1.3
nCHG: R13.1, U1.9, U4.33
nPGOOD: R19.1, U1.7, U4.34
pos: LED2.2, R20.2

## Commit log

2026-06-01 Set power and BLE LED colors
2026-06-01 Add Atopile schematic for FlySys hardware
    [BULETM-SMD_ESP32-S3-MINI-1-N8.step, C0603_L1.6-W0.8-H0.8.step, LED0603-RD-YELLOW.STEP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]
2026-06-01 Add local BMP581 footprint
    [default.kicad_pcb]
2026-06-02 Doc, gerber, kicad
    [default.kicad_pcb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]
2026-06-02 Add hard-off power path and bootloader buttons
    [default.kicad_pcb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]
2026-06-03 Boot, reset, USB protection
    [default.kicad_pcb, flysys_vario.kicad_sch, flysys_vario_digikey_bom.csv]
2026-06-03 Led indicator changes
2026-06-03 Point to digikey.si
    [flysys_vario.kicad_sch, flysys_vario_digikey_bom.csv]
2026-06-08 Change ESP add antenna
    [flysys_vario.kicad_sch, flysys_vario_digikey_bom.csv]
